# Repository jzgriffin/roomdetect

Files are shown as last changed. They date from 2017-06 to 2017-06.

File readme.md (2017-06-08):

# CS120B

This repository contains the quarter project that I completed in CS120B,
Introduction to Embedded Systems, at UC Riverside in spring 2017.  The
project was a room detector using a trained statistical model running on
a pair of ATmega1284p microcontrollers.  For more information, see the
full report in the report directory.

## Ownership

I acknowledge all content contained herein, excluding template or
example code, is my own original work.

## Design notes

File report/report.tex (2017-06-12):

\documentclass{article}

\usepackage{etoolbox}
\usepackage{float}
\usepackage{geometry}
\usepackage{graphicx}
\usepackage{pgf}
\usepackage{tikz}

\newtoggle{TASKSPECONLY}

\geometry{margin=1in}

\graphicspath{ {figures/}{photos/} }

\usetikzlibrary{arrows}
\usetikzlibrary{automata}
\usetikzlibrary{fit}
\usetikzlibrary{positioning}
\tikzset{initial text={}}

\title{Report: Room Detector}
\author{Jeremiah Griffin}
\date{Spring 2017}

\begin{document}

\pagenumbering{gobble}
\maketitle
\newpage

\pagenumbering{roman}
\tableofcontents
\newpage

\pagenumbering{arabic}

\section{Introduction}

The room detector uses inputs from several sensors to determine what
room or environment the device is currently in.  It uses a statistical
model to associate ambient factors with a user-defined room number.  The
network must be trained by the user before it may be used.  This is done
online by placing the device in each room to be detected, entering
training mode, associating either a new or existing room number with the
training data, and then moving the device through the room.  The longer
the device is trained, the more accurate its classifications become.
Once training is complete, the device may enter detection mode and be
moved between any of the trained rooms.  If brought to an untrained
room, it will make its best guess at classifying the room as one that
was trained.

\begin{figure}[h]
  \centering
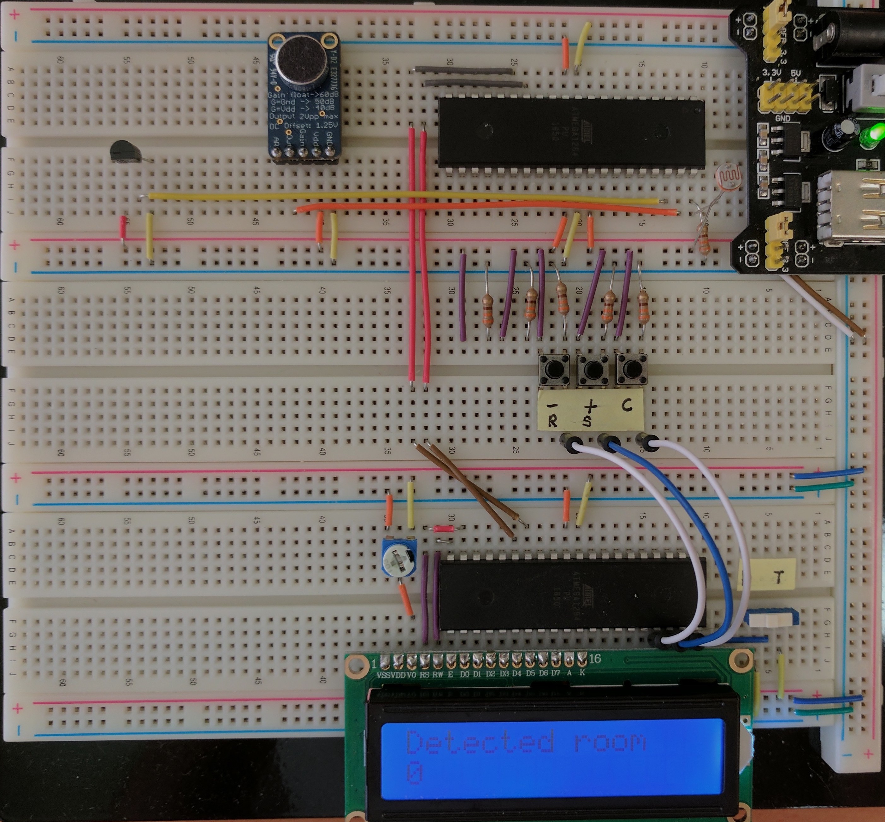
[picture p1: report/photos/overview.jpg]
  \noindent
  \caption{Overview photo of project hardware}
  \label{photo:1}
\end{figure}

\section{Hardware}

\subsection{Parts}

The hardware components that were used in this project are listed below.
The equipment that was not taught as part of the course material is
listed in bold.

\begin{table}[h!]
  \centering
  \begin{tabular}{llr}
    Part Number & Component & Quantity \\
    \hline
    ATmega1284p             & Microcontroller                  & 2 \\
                            & SPDT toggle switch               & 1 \\
                            & SPST push-down button            & 3 \\
                            & 10K\Omega\ trimmer potentiometer & 1 \\
                            & 330\Omega\ 10\% resistor         & 4 \\
                            & CdS photoresistor                & 1 \\
    LCM-S01602DTR/M         & Liquid crystal display           & 1 \\
    \textbf{TMP36}          & Temperature sensor               & 1 \\
    \textbf{CMA-4544PF-W}   & Electret microphone              & 1 \\
    \textbf{MAX9814}        & Microphone amplifier             & 1
  \end{tabular}
  \caption{Listing of parts used in design}
  \label{table:1}
\end{table}

\subsection{Pinout}

\begin{figure}[H]
  \centering
  \noindent
  \caption{Pinout and schematic for project}
  \label{schematic:1}
\end{figure}

\section{Software}

The software designed for this project was implemented using the PES
standard.  The overall design as a task diagram is included below.

\begin{figure}[H]
  \centering
  \noindent
  \caption{Task diagram for project}
  \label{task:1}
\end{figure}

The master and compute tasks run on their respective microcontrollers.
The common tasks run independently on both microcontrollers, being part
of a static library linked to by both microcontroller applications and
instantiated in their task schedulers.  The inputs and outputs for the
common LCD, USART TX, USART RX, and packet RX tasks were excluded from
this diagram for brevity but are documented in their task descriptions.

In the following sections, the individual tasks from the above diagram
are briefly described in addition to their inputs and outputs.  The
state machines for these tasks are presented in appendix \ref{app.sm}.

\subsection{Tasks}

\toggletrue{TASKSPECONLY}

\subsubsection{Master Mode Task}
\input{figures/master_mode_task.tex}

Sets \verb#device_mode# to \verb#DETECTION# if \verb#PA0# is low and to
\verb#TRAINING# if it's high.  This controls which of the detection and
training tasks is enabled.

\subsubsection{Master Detection Task}
\input{figures/master_detection_task.tex}

Operates when \verb#device_mode# is \verb#DETECTION#.  Receives
detection packets from the compute microcontroller.  Responds to the
save, reset, and erase buttons by sending the appropriate packets to the
compute microcontroller to adjust the model.

\subsubsection{Master Training Task}
\input{figures/master_training_task.tex}

Operates when \verb#device_mode# is \verb#TRAINING#.  Responds to the
increment, decrement, and confirm buttons by adjusting the training room
and sending the appropriate packets to the compute microcontroller to
begin and end training.  Sets \verb#is_training# to true when training.

\subsubsection{Master Display Task}
\input{figures/master_display_task.tex}

Outputs messages to the LCD according to the current state and detected
or training room.  Controlled by the detection and training tasks.

\subsubsection{Compute Mode Task}
\input{figures/compute_mode_task.tex}

Sets \verb#device_mode# to \verb#DETECTION# when a stop-training packet
is received and to \verb#TRAINING# when a start-training packet is
received.  Sets \verb#training_room# to the room indicated in the
start-training packet.

\subsubsection{Compute Reading Task}
\input{figures/compute_reading_task.tex}

Samples from the analog inputs in sequence when
\verb#should_poll_readings# is true to create the \verb#reading_vector#.
Calculates the mean of 16 samples through time to smooth noise.
Indicates when the reading vector is populated by setting
\verb#are_readings_ready# to true.

\subsubsection{Compute Detection Task}
\input{figures/compute_detection_task.tex}

Classifies the current reading vector using the classification model
when \verb#are_readings_ready# is high and \verb#device_mode# is
\verb#DETECTION#.  Outputs the classification result to
\verb#detected_room#.

\subsubsection{Compute Training Task}
\input{figures/compute_training_task.tex}

Integrates the current reading vector into the classification model when
\verb#are_readings_ready# is high and \verb#device_mode# is
\verb#TRAINING#.

\subsubsection{Common LCD Task}
\input{figures/common_lcd_task.tex}

Clears the LCD when \verb#should_lcd_clear# is true.  Writes the
contents of \verb#lcd_buffer# to the LCD at \verb#lcd_position# when
\verb#should_lcd_write# is true.  Sets \verb#is_lcd_ready# to true when
the current operation is complete.

\subsubsection{Common USART TX Task}
\input{figures/common_usart_tx_task.tex}

Transmits bytes over USART from the TX queue.

\subsubsection{Common USART RX Task}
\input{figures/common_usart_rx_task.tex}

Receives bytes from USART into the RX queue.

\subsubsection{Common Packet RX Task}
\input{figures/common_usart_packet_rx_task.tex}

Identifies and receives packets from the USART RX queue into the packet
RX queue.  When active, non-packet bytes are discarded from the
queue--thus only packet communication is possible when scheduled.

\section{Complexities}

\subsection{Complete}

\begin{itemize}

  \item Using EEPROM to persist the classification model state

  \item Using USART to offload computation to a dedicated
    microcontroller

  \item Using ADC multiplexing to collect analog readings from multiple
    sensors

  \item Using a temperature sensor and microphone obtained outside of
    the lab kit

  \item Using a statistical model to perform input classification using
    fixed-point arithmetic

\end{itemize}

\subsection{Incomplete}

\begin{itemize}

  \item Using a neural network to perform input classification using
    fixed-point arithmetic \\
    This complexity could not be completed due to hardware limitations.
    Its role in the project was instead filled by the statistical model
    listed above.  The intended design for the neural network was a
    multi-layer feed-forward network, with one input layer of size 4,
    one hidden layer of size 10 with a linear activation function, one
    hidden layer of size 10 with a hyperbolic tangent activation
    function, one hidden layer of size 16 with a linear activation
    function, and one output layer of size 16 with a softmax activation
    function.  This topology was chosen as the best for fulfilling the
    goal of classifying three inputs, with one bias input, into one of
    16 outputs.  However, this network proved too large for the ATmega
    to process.  When including the amount of memory necessary for
    storing training state, the network became too large for storage in
    the ATmega's 16 kilobyte SRAM.  Additionally, even using fixed-point
    arithmetic in place of traditional floating point, the times for
    classification became slower than was considered acceptable and the
    times for training made it obvious that training would only be
    possible offline using a faster device, which was deemed to be
    beyond the scope of this project.  As a result of these limitations,
    the neural network was replaced with a simpler statistical model at
    the cost of accuracy and robustness when faced with input noise.

\end{itemize}

\section{Links}

\begin{description}

  \item [Demonstration Video] https://youtu.be/Kw6NZRzlpkQ

  \item [GitHub Repository] https://github.com/nokurn/roomdetect

\end{description}

\section{Known Issues}

\begin{itemize}

  \item The classification algorithm does not cope well with noise and
    may confuse environments with a large degree of noise as being
    equivalent regardless of the specifics of that noise.

  \item The temperature sensor is not measured with sufficient precision
    for its readings to adequately influence the results of the
    classification.

  \item The microphone primarily distinguishes between noisy and quiet
    environments with no consideration of the qualities of the sound
    such as timbre and pitch.

  \item The classifier most heavily relies on the measurements from the
    photo-resistor, despite unbiased treatment of all readings in the
    input vector.  This is likely due to the aforementioned reasons:
    low analog precision and the need for pre-processing of some
    readings.

\end{itemize}

\section{Future Work}

\begin{itemize}

  \item The largest improvement might come from replacing the compute
    microcontroller with a higher-power compute unit, possibly
    integrating floating-point arithmetic, and using a more robust
    classification model such as a neural network.

  \item By using an external analog-digital converter with higher
    precision, or simply replacing the ATmega with a microcontroller
    with a higher-precision integrated ADC, sensors with small output
    ranges would contribute more to the accuracy and confidence of the
    device's classifications.  This would reflect immediately in the
    ability of the device to distinguish between environments with
    slightly different temperatures.

  \item Applying a Fourier transform to the microphone signal and using
    the individual components as input to the classifier would improve
    the quality of classifications with regard to environmental sounds.
    For example, if one room contains several computers with spinning
    fans and another room has a single ceiling fan, yet the volume level
    in both rooms is similar, a Fourier analysis of the sound waves
    would enable the classifier to distinguish between the two by the
    timbre and pitch of the sound in addition to its loudness.

  \item Adding additional sensors would increase the size of the
    classifier's feature vector and its accuracy.  Barometric pressure,
    humidity, altitude, or even GPS would be likely candidates for
    inclusion in the system.

\end{itemize}

\appendix

\section{Appendix: State Machines}
\label{app.sm}

\togglefalse{TASKSPECONLY}

In the following state machines, transitions without conditions should
be interpreted to be else-transitions unless the state only has one
outgoing transition, in which case the transition is unconditional.

\subsection{Master Microcontroller}
\label{app.sm.master}

\begin{figure}[H]
  \caption{State machine for master mode task}
  \input{figures/master_mode_task.tex}
  \label{sm:1}
\end{figure}

\begin{figure}[H]
  \caption{State machine for master detection task}
  \input{figures/master_detection_task.tex}
  \label{sm:2}
\end{figure}

\begin{figure}[H]
  \caption{State machine for master training task}
  \input{figures/master_training_task.tex}
  \label{sm:3}
\end{figure}

\begin{figure}[H]
  \caption{State machine for master display task}
  \input{figures/master_display_task.tex}
  \label{sm:4}
\end{figure}

\subsection{Compute Microcontroller}
\label{app.sm.compute}

\begin{figure}[H]
  \caption{State machine for compute mode task}
  \input{figures/compute_mode_task.tex}
  \label{sm:5}
\end{figure}

\begin{figure}[H]
  \caption{State machine for compute reading task}
  \input{figures/compute_reading_task.tex}
  \label{sm:6}
\end{figure}

\begin{figure}[H]
  \caption{State machine for compute detection task}
  \input{figures/compute_detection_task.tex}
  \label{sm:7}
\end{figure}

\begin{figure}[H]
  \caption{State machine for compute training task}
  \input{figures/compute_training_task.tex}
  \label{sm:8}
\end{figure}

\subsection{Common Infrastructure}
\label{app.sm.common}

\begin{figure}[H]
  \caption{State machine for common LCD task}
  \input{figures/common_lcd_task.tex}
  \label{sm:9}
\end{figure}

\begin{figure}[H]
  \caption{State machine for common USART TX task}
  \input{figures/common_usart_tx_task.tex}
  \label{sm:10}
\end{figure}

\begin{figure}[H]
  \caption{State machine for common USART RX task}
  \input{figures/common_usart_rx_task.tex}
  \label{sm:11}
\end{figure}

\begin{figure}[H]
  \caption{State machine for common USART packet RX task}
  \input{figures/common_usart_packet_rx_task.tex}
  \label{sm:12}
\end{figure}

\end{document}

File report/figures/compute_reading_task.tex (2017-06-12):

\begin{flushleft}
  \begin{description}
    \item [Input]
      \verb#should_poll_readings: bool#;
      \verb#adc#
    \item [Output]
      \verb#reading_vector: accum[]#;
      \verb#are_readings_ready: bool#
    \item [Local]
      \verb#readings: accum[]#;
      \verb#index: size#;
      \verb#samples: size#
    \item [Period] 1 ms
  \end{description}
\end{flushleft}

\iftoggle{TASKSPECONLY}{}
{
\begin{center}
  \begin{tikzpicture}[->,>=stealth',
      shorten >=1pt,
      node distance=41mm,
      auto,
      on grid,
      semithick]

    \node[state,initial]
      (Initial) {Initial};
    \node[state]
      (Configure) [right=of Initial] {Configure};
    \node[state]
      (Standby) [right=of Configure] {Standby};
    \node[state]
      (Poll) [below of=Standby] {Poll};
    \node[state]
      (Start) [below of=Initial] {Start};
    \node[state]
      (Wait) [below of=Start] {Wait};
    \node[state]
      (Read) [below of=Poll] {Read};
    \node[state]
      (Next) [below of=Read] {Next};
    \node[state]
      (Output) [below of=Wait] {Output};

    \path[->]
      (Initial) edge node {} (Configure)
      (Configure) edge node {} (Standby)
      (Standby) edge node {should\_poll\_readings} (Poll)
      (Standby) edge [loop right] node {} (Standby)
      (Poll) edge node {} (Start)
      (Start) edge node {} (Wait)
      (Wait) edge node {is\_adc\_ready()} (Read)
      (Wait) edge [loop left] node {} (Wait)
      (Read) edge [align=left] node {index ==\\MODEL\_VECTOR\_SIZE} (Next)
      (Read) edge node {} (Start)
      (Next) edge [align=left] node {samples ==\\SAMPLE\_SIZE} (Output)
      (Next) edge [bend left] node {} (Start)
      (Output) edge [bend left=20] node {} (Standby);

  \end{tikzpicture}
\end{center}

}

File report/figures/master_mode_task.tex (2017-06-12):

\begin{flushleft}
  \begin{description}
    \item [Input]
      \verb#PA0#
    \item [Output]
      \verb#device_mode: enum#
    \item [Period] 16 ms
  \end{description}
\end{flushleft}

\iftoggle{TASKSPECONLY}{}
{
\begin{tikzpicture}[->,>=stealth',
    shorten >=1pt,
    node distance=40mm,
    auto,
    on grid,
    semithick]

  \node[state,initial]
    (Initial) {Initial};
  \node[state]
    (Configure) [right=of Initial] {Configure};
  \node[state,label={[align=left]above:{device\_mode =\\DETECTION}}]
    (Detection) [right=of Configure] {Detection};
  \node[state,label={[align=left]above:{device\_mode =\\TRAINING}}]
    (Training) [right=of Detection] {Training};

  \path[->]
    (Initial)   edge node {}     (Configure)
    (Configure) edge node {!PA0} (Detection)
    (Configure) edge [bend right=90] node [below] {PA0}  (Training)
    (Detection) edge [loop below] node {!PA0} (Detection)
    (Detection) edge [bend left] node {PA0}  (Training)
    (Training)  edge [bend left] node {!PA0} (Detection)
    (Training)  edge [loop right] node {PA0}  (Training);

\end{tikzpicture}
}

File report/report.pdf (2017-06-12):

# Report: Room Detector

Jeremiah Griffin

Spring 2017

## Contents

1 Introduction | 1
2 Hardware | 2
3 Software | 3
4 Complexities | 6
5 Links | 7
6 Known Issues | 7
7 Future Work | 7
A Appendix: State Machines | 7

i

## 1 Introduction

The room detector uses inputs from several sensors to determine what room or environment the device is currently in. It uses a statistical model to associate ambient factors with a user-defined room number. The network must be trained by the user before it may be used. This is done online by placing the device in each room to be detected, entering training mode, associating either a new or existing room number with the training data, and then moving the device through the room. The longer the device is trained, the more accurate its classifications become. Once training is complete, the device may enter detection mode and be moved between any of the trained rooms. If brought to an untrained room, it will make its best guess at classifying the room as one that was trained.


Figure 1: Overview photo of project hardware

## 2 Hardware

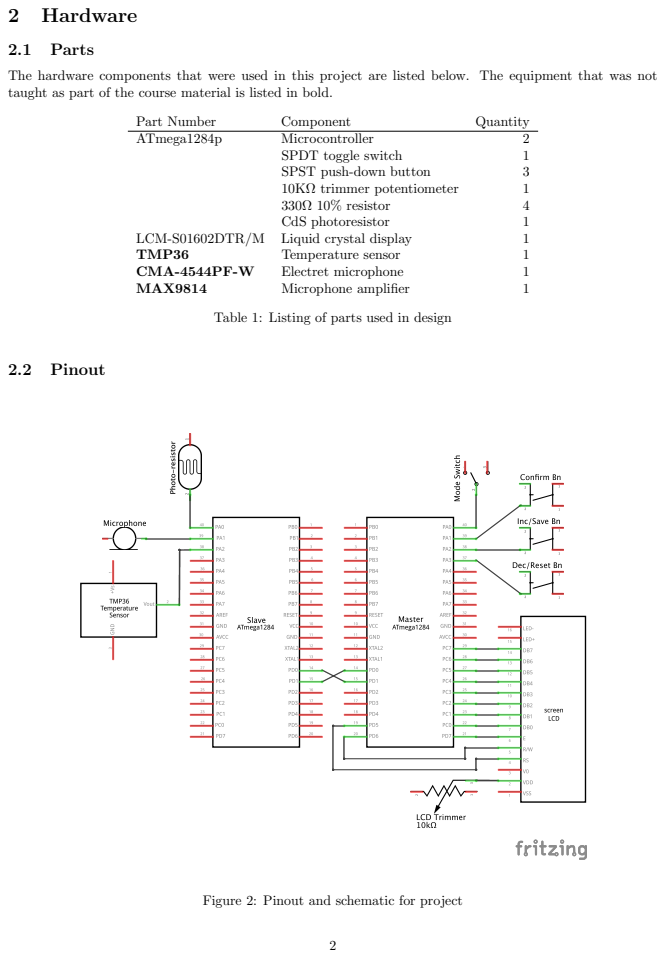
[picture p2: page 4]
2.1 Parts; Part Number; Component; Quantity; ATmega1284p; Microcontroller; SPDT toggle switch; SPST push-down button; 10KΩ trimmer potentiometer; 330Ω 10% resistor; CdS photoresistor; LCM-S01602DTR/M; Liquid crystal display; TMP36; Temperature sensor; CMA-4544PF-W; Electret microphone; MAX9814; Microphone amplifier; 2.2 Pinout

The hardware components that were used in this project are listed below. The equipment that was not
taught as part of the course material is listed in bold.

Table 1: Listing of parts used in design

Figure 2: Pinout and schematic for project

## 3 Software

The software designed for this project was implemented using the PES standard. The overall design as a

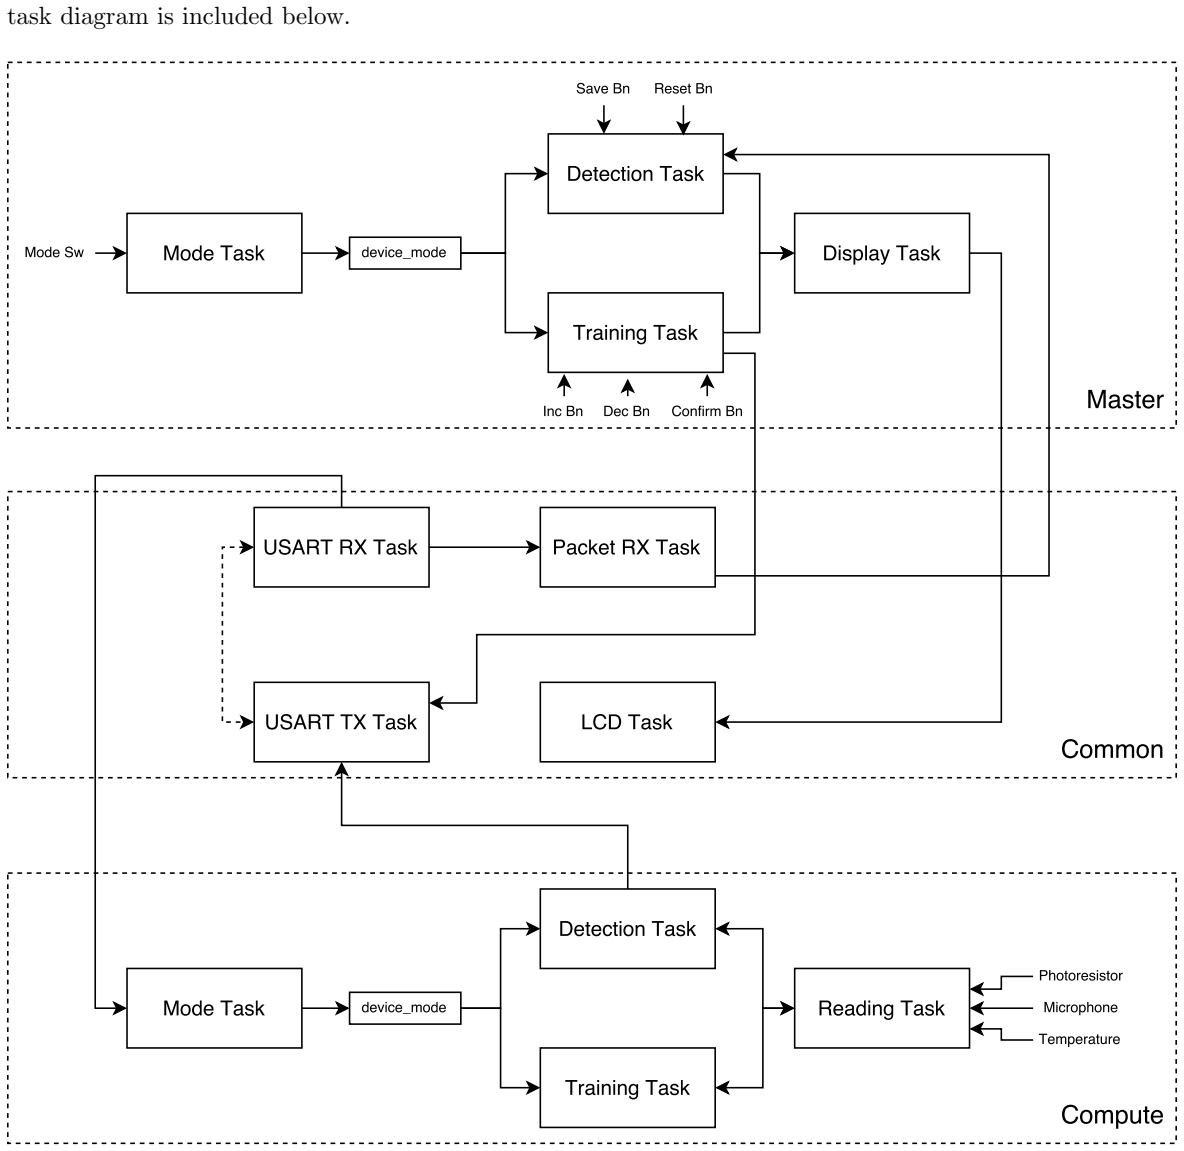
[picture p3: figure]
task diagram is included below.

Figure 3: Task diagram for project

The master and compute tasks run on their respective microcontrollers. The common tasks run independently on both microcontrollers, being part of a static library linked to by both microcontroller applications and instantiated in their task schedulers. The inputs and outputs for the common LCD, USART TX, US-ART RX, and packet RX tasks were excluded from this diagram for brevity but are documented in their task descriptions.
In the following sections, the individual tasks from the above diagram are briefly described in addition to their inputs and outputs. The state machines for these tasks are presented in appendix A.

### 3.1 Tasks

### 3.1.1 Master Mode Task

Input PA0

Output device_mode: enum

Period 16 ms

Sets device_mode to DETECTION if PA0 is low and to TRAINING if it’s high. This controls which of the detection and training tasks is enabled.

### 3.1.2 Master Detection Task

Input device_mode; PA2; PA3

Output detected_room: uint8; usart_tx_queue

Local tick_count: uint16

Period 20 ms

Operates when device_mode is DETECTION. Receives detection packets from the compute microcontroller. Responds to the save, reset, and erase buttons by sending the appropriate packets to the compute microcontroller to adjust the model.

### 3.1.3 Master Training Task

Input device_mode; PA1; PA2; PA3

Output training_room: uint8; is_training: bool; usart_tx_queue

Local tick_count: uint16

Period 20 ms

Operates when device_mode is TRAINING. Responds to the increment, decrement, and confirm buttons by adjusting the training room and sending the appropriate packets to the compute microcontroller to begin and end training. Sets is_training to true when training.

### 3.1.4 Master Display Task

Input detected_room; training_room; is_training; should_display_save; should_display_reset; should_display_erase; is_lcd_ready

Output should_lcd_clear; should_lcd_write; lcd_buffer; lcd_position

Local last_room: uint8

Period 20 ms

Outputs messages to the LCD according to the current state and detected or training room. Controlled by the detection and training tasks.

### 3.1.5 Compute Mode Task

Input usart_packet_rx_queue

Output device_mode: enum; training_room: uint8

Period 16 ms

Sets device_mode to DETECTION when a stop-training packet is received and to TRAINING when a start-training packet is received. Sets training_room to the room indicated in the start-training packet.

### 3.1.6 Compute Reading Task

Input should_poll_readings: bool; adc

Output reading_vector: accum[]; are_readings_ready: bool

Local readings: accum[]; index: size; samples: size

Period 1 ms

Samples from the analog inputs in sequence when should_poll_readings is true to create the reading_vector. Calculates the mean of 16 samples through time to smooth noise. Indicates when the reading vector is populated by setting are_readings_ready to true.

### 3.1.7 Compute Detection Task

Input device_mode; reading_vector; are_readings_ready

Output detected_room: uint8; should_poll_readings

Period 16 ms

Classifies the current reading vector using the classification model when are_readings_ready is high and device_mode is DETECTION. Outputs the classification result to detected_room.

### 3.1.8 Compute Training Task

Input device_mode; reading_vector; are_readings_ready; training_room: uint8

Output should_poll_readings

Period 16 ms

Integrates the current reading vector into the classification model when are_readings_ready is high and device_mode is TRAINING.

### 3.1.9 Common LCD Task

Input should_lcd_clear: bool; should_lcd_write: bool; lcd_buffer: char[]; lcd_position: uint8

Output is_lcd_ready: bool

Local index: size

Period 2 ms

Clears the LCD when should_lcd_clear is true. Writes the contents of lcd_buffer to the LCD at lcd_position when should_lcd_write is true. Sets is_lcd_ready to true when the current operation is complete.

### 3.1.10 Common USART TX Task

Input usart_tx_queue: uint8[]; usart_tx_queue_size: size; usart_tx_queue_head: size; usart_tx_queue_tail: size

Output usart_tx_queue

Period 1 ms

Transmits bytes over USART from the TX queue.

### 3.1.11 Common USART RX Task

Input usart_rx_queue

Output usart_rx_queue: uint8[]; usart_rx_queue_size: size; usart_rx_queue_head: size; usart_rx_queue_tail: size

Period 1 ms

Receives bytes from USART into the RX queue.

### 3.1.12 Common Packet RX Task

Input usart_rx_queue

Output usart_packet_rx_queue: usart_packet[]; usart_packet_rx_queue_size: size; usart_packet_rx_queue_head: size; usart_packet_rx_queue_tail: size

Locals packet: uint8[]; size: size; target_size: size; data_size: size

Period 1 ms

Identifies and receives packets from the USART RX queue into the packet RX queue. When active, non-packet bytes are discarded from the queue–thus only packet communication is possible when scheduled.

## 4 Complexities

### 4.1 Complete

- Using EEPROM to persist the classification model state
- Using USART to offload computation to a dedicated microcontroller
- Using ADC multiplexing to collect analog readings from multiple sensors
- Using a temperature sensor and microphone obtained outside of the lab kit
- Using a statistical model to perform input classification using fixed-point arithmetic

### 4.2 Incomplete

- Using a neural network to perform input classification using fixed-point arithmetic
This complexity could not be completed due to hardware limitations. Its role in the project was instead filled by the statistical model listed above. The intended design for the neural network was a multi-layer feed-forward network, with one input layer of size 4, one hidden layer of size 10 with a linear activation function, one hidden layer of size 10 with a hyperbolic tangent activation function, one hidden layer of size 16 with a linear activation function, and one output layer of size 16 with a softmax activation function. This topology was chosen as the best for fulfilling the goal of classifying three inputs, with one bias input, into one of 16 outputs. However, this network proved too large for the ATmega to process. When including the amount of memory necessary for storing training state, the network became too large for storage in the ATmega’s 16 kilobyte SRAM. Additionally, even using fixed-point arithmetic in place of traditional floating point, the times for classification became slower than was considered acceptable and the times for training made it obvious that training would only be possible offline using a faster device, which was deemed to be beyond the scope of this project. As a result of these limitations, the neural network was replaced with a simpler statistical model at the cost of accuracy and robustness when faced with input noise.

## 5 Links

Demonstration Video https://youtu.be/Kw6NZRzlpkQ

GitHub Repository https://github.com/nokurn/roomdetect

## 6 Known Issues

- The classification algorithm does not cope well with noise and may confuse environments with a large degree of noise as being equivalent regardless of the specifics of that noise.
- The temperature sensor is not measured with sufficient precision for its readings to adequately influence the results of the classification.
- The microphone primarily distinguishes between noisy and quiet environments with no consideration of the qualities of the sound such as timbre and pitch.
- The classifier most heavily relies on the measurements from the photo-resistor, despite unbiased treatment of all readings in the input vector. This is likely due to the aforementioned reasons: low analog precision and the need for pre-processing of some readings.

## 7 Future Work

- The largest improvement might come from replacing the compute microcontroller with a higher-power compute unit, possibly integrating floating-point arithmetic, and using a more robust classification model such as a neural network.
- By using an external analog-digital converter with higher precision, or simply replacing the ATmega with a microcontroller with a higher-precision integrated ADC, sensors with small output ranges would contribute more to the accuracy and confidence of the device’s classifications. This would reflect immediately in the ability of the device to distinguish between environments with slightly different temperatures.
- Applying a Fourier transform to the microphone signal and using the individual components as input to the classifier would improve the quality of classifications with regard to environmental sounds. For example, if one room contains several computers with spinning fans and another room has a single ceiling fan, yet the volume level in both rooms is similar, a Fourier analysis of the sound waves would enable the classifier to distinguish between the two by the timbre and pitch of the sound in addition to its loudness.
- Adding additional sensors would increase the size of the classifier’s feature vector and its accuracy. Barometric pressure, humidity, altitude, or even GPS would be likely candidates for inclusion in the system.

## A Appendix: State Machines

In the following state machines, transitions without conditions should be interpreted to be else-transitions unless the state only has one outgoing transition, in which case the transition is unconditional.

A.1 Master Microcontroller

Figure 4: State machine for master mode task

Input PA0

Output device_mode: enum

Period 16 ms

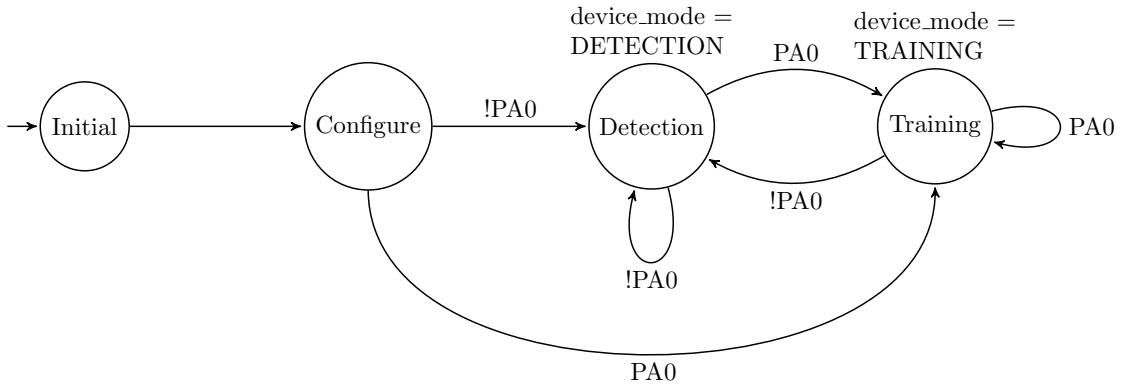
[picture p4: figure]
Initial; Configure; Detection; device mode = DETECTION; Training; device mode = TRAINING

Figure 5: State machine for master detection task

Input device_mode; PA2; PA3

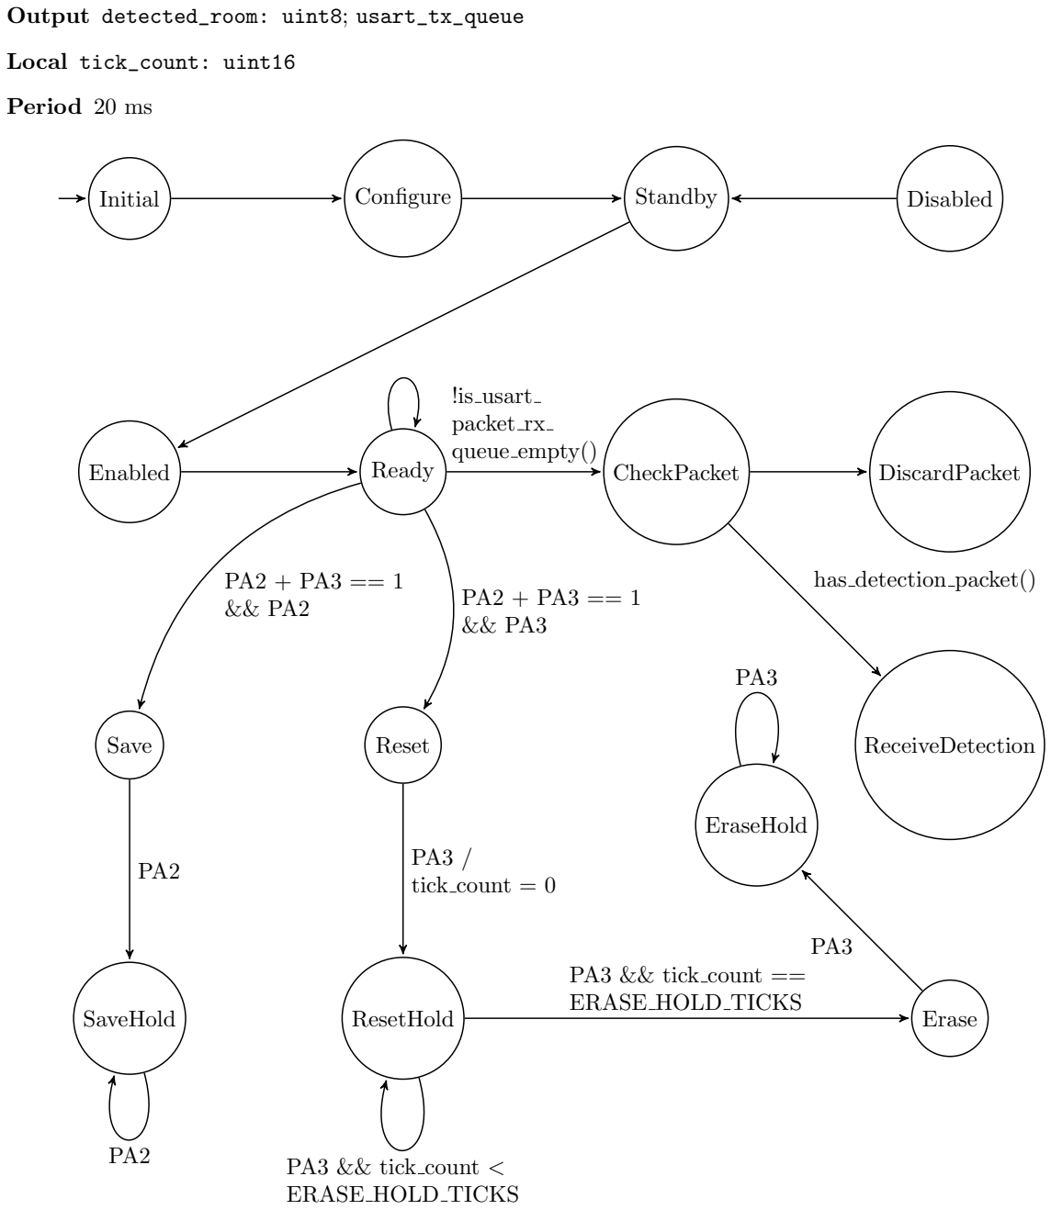
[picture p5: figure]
Output detected_room: uint8; usart_tx_queue; Local tick_count: uint16; Period 20 ms; Initial; Configure; Standby; Disabled; Enabled; Ready; Reset; ResetHold; Save; SaveHold; CheckPacket; DiscardPacket; ReceiveDetection; Erase; EraseHold; !is usart packet rx queue empty(); PA3 / tick count = 0; PA3 && tick count == ERASE HOLD TICKS; PA3 && tick count < ERASE HOLD TICKS; has detection packet()

The following transitions have been omitted for clarity: from all states to the Disabled state, under the condition that device mode != DETECTION; and the else-transitions from the DiscardPacket, ReceiveDetection, Save, Reset, Erase, SaveHold, ResetHold, and EraseHold states to the Ready state.

Figure 6: State machine for master training task

Input device_mode; PA1; PA2; PA3

Output training_room: uint8; is_training: bool; usart_tx_queue

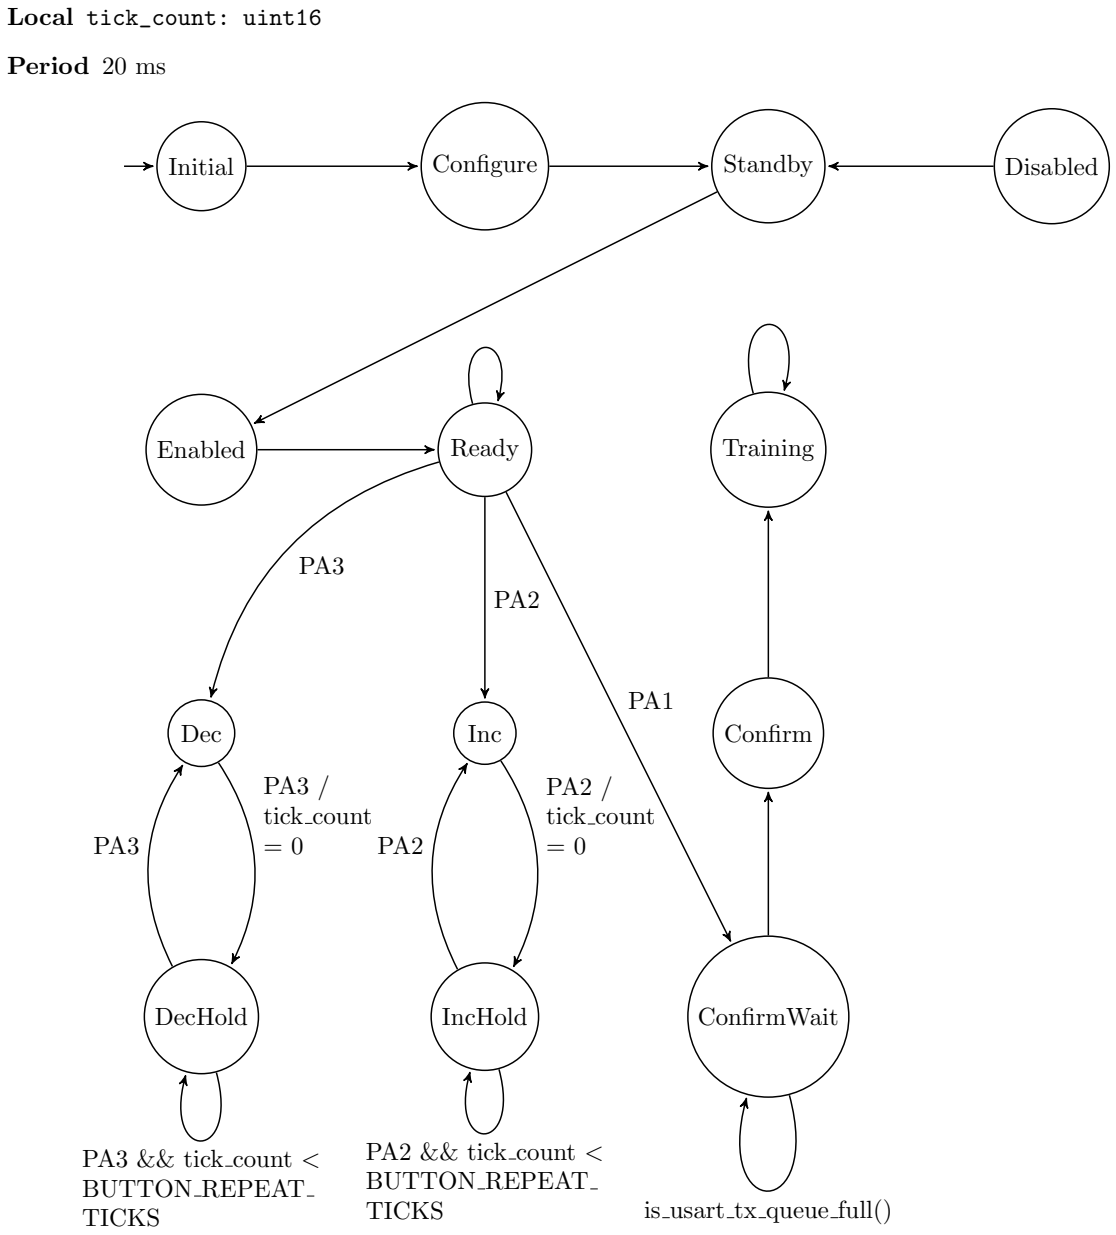
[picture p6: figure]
Local tick_count: uint16; Period 20 ms; Initial; Configure; Standby; Disabled; Enabled; Ready; Inc; IncHold; Dec; DecHold; Training; Confirm; ConfirmWait; PA2 / tick count; PA2 && tick count < BUTTON REPEAT TICKS; PA3 / tick count; PA3 && tick count < BUTTON REPEAT; TICKS; is usart tx queue full()

The following transitions have been omitted for clarity: from all states to the Disabled state, under the condition that device mode != TRAINING; and the else-transitions from the Inc, IncHold, Dec, and DecHold states to the Ready state. The transition conditions from the Ready state to the Dec, Inc, and ConfirmWait states are also conjoined with the condition that PA1 + PA2 + PA3 == 1. The transition conditions from the DecHold and IncHold states to the Dec and Inc states, respectively, are also conjoined with the condition that tick count == BUTTON REPEAT TICKS.

Figure 7: State machine for master display task

Input detected_room; training_room; is_training; should_display_save; should_display_reset; should_display_erase; is_lcd_ready

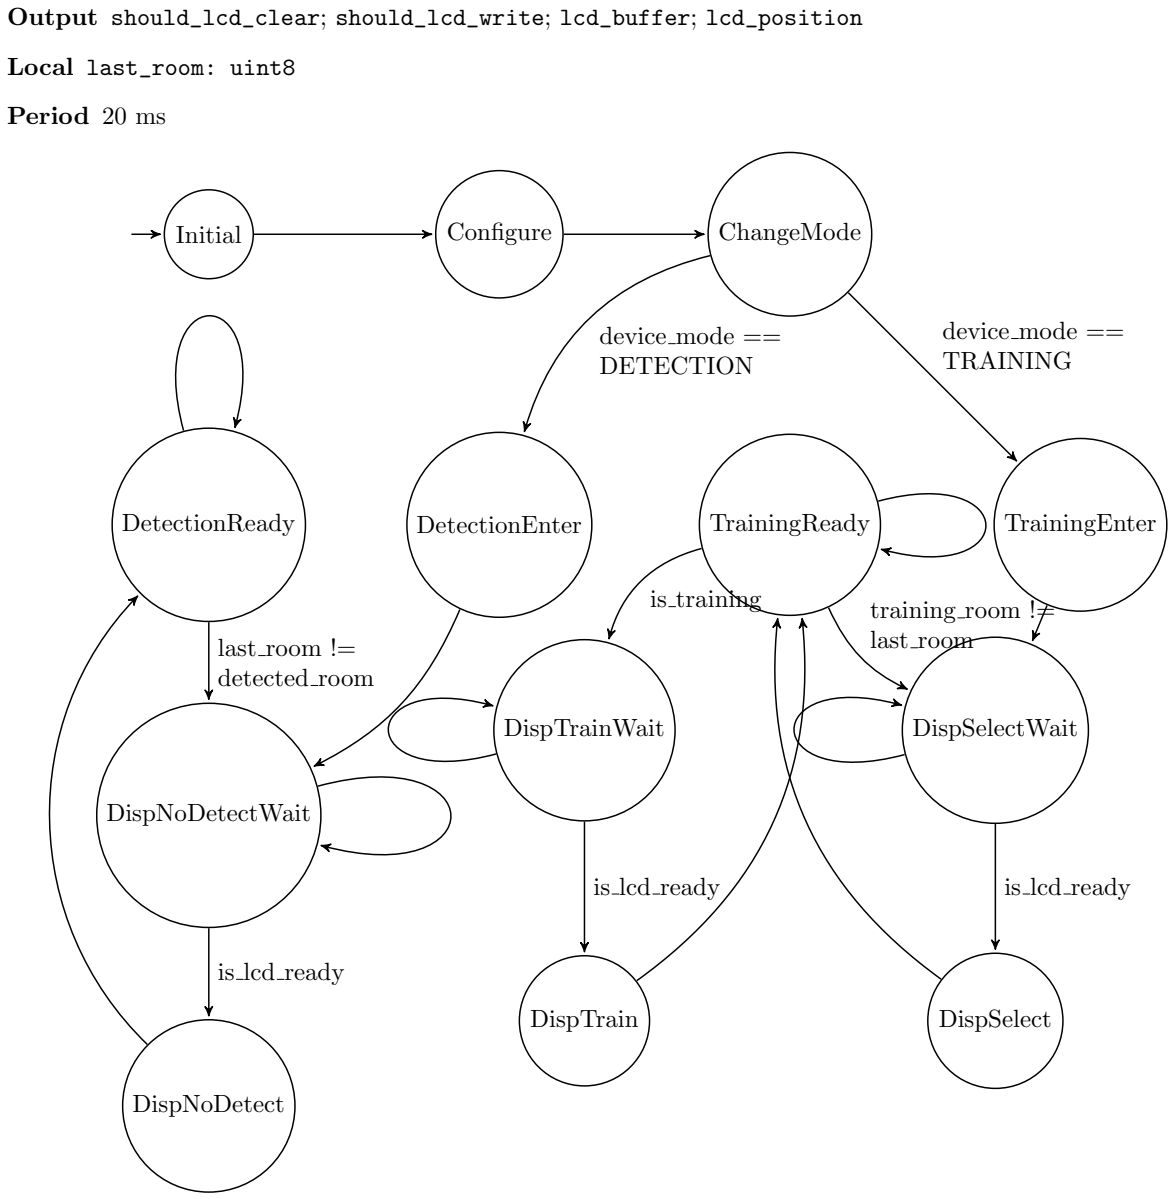
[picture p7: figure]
Output should_lcd_clear; should_lcd_write; lcd_buffer; lcd_position; Local last_room: uint8; Period 20 ms; Initial; Configure; ChangeMode; DetectionReady; DetectionEnter; DispNoDetectWait; DispNoDetect; TrainingReady; TrainingEnter; DispSelectWait; DispSelect; DispTrainWait; DispTrain; device mode == DETECTION; device mode == TRAINING; last room != detected room; is lcd ready; training room != last room; is training

The following transitions have been omitted for clarity: from all states to the ChangeMode state, under the condition that device mode is different from the expected mode for the given state. The DispNoDetectWait and DispNoDetect states are duplicated, including transitions, for the following similar states: Detect, Save, Reset, and Erase. These redundant states have been omitted for clarity.

A.2 Compute Microcontroller

Figure 8: State machine for compute mode task

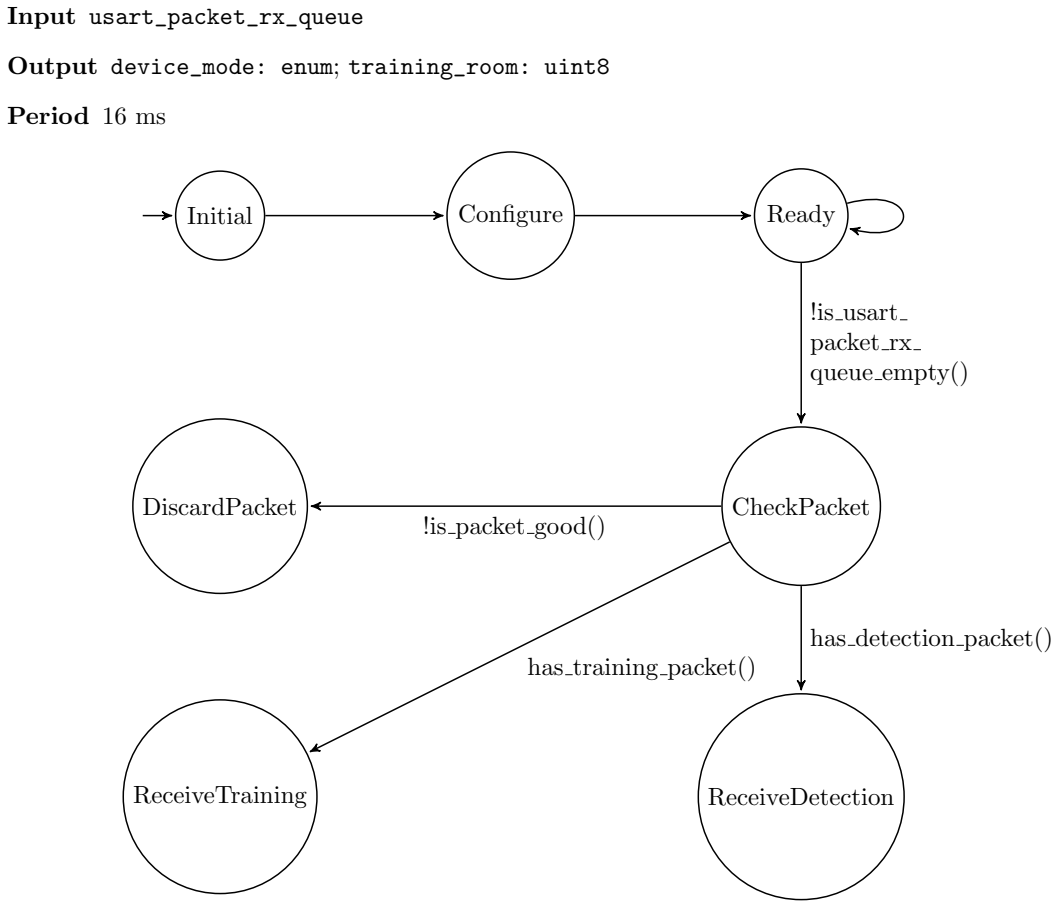
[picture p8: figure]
Input usart_packet_rx_queue; Output device_mode: enum; training_room: uint8; Period 16 ms; Initial; Configure; Ready; DiscardPacket; CheckPacket; ReceiveTraining; ReceiveDetection; !is usart packet rx queue empty(); !is packet good(); has detection packet(); has training packet()

The following transitions have been omitted for clarity: from the DiscardPacket, ReceiveDetection, and ReceiveTraining states to the Ready state under any condition.

Figure 9: State machine for compute reading task

Input should_poll_readings: bool; adc

Output reading_vector: accum[]; are_readings_ready: bool

Local readings: accum[]; index: size; samples: size

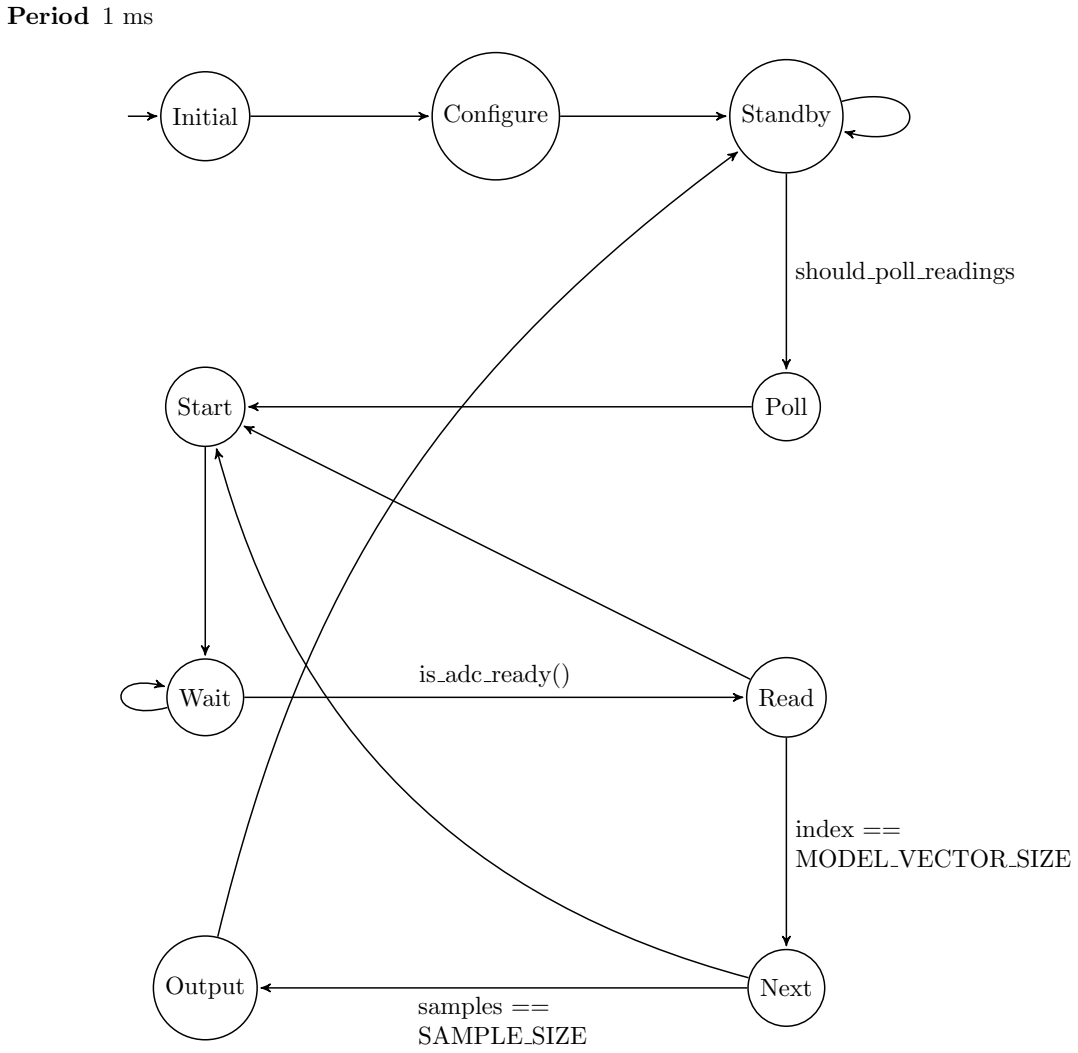
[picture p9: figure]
Period 1 ms; Initial; Configure; Standby; Start; Poll; Wait; Read; Output; Next; should poll readings; is adc ready(); index == MODEL VECTOR SIZE; samples == SAMPLE SIZE

Figure 10: State machine for compute detection task

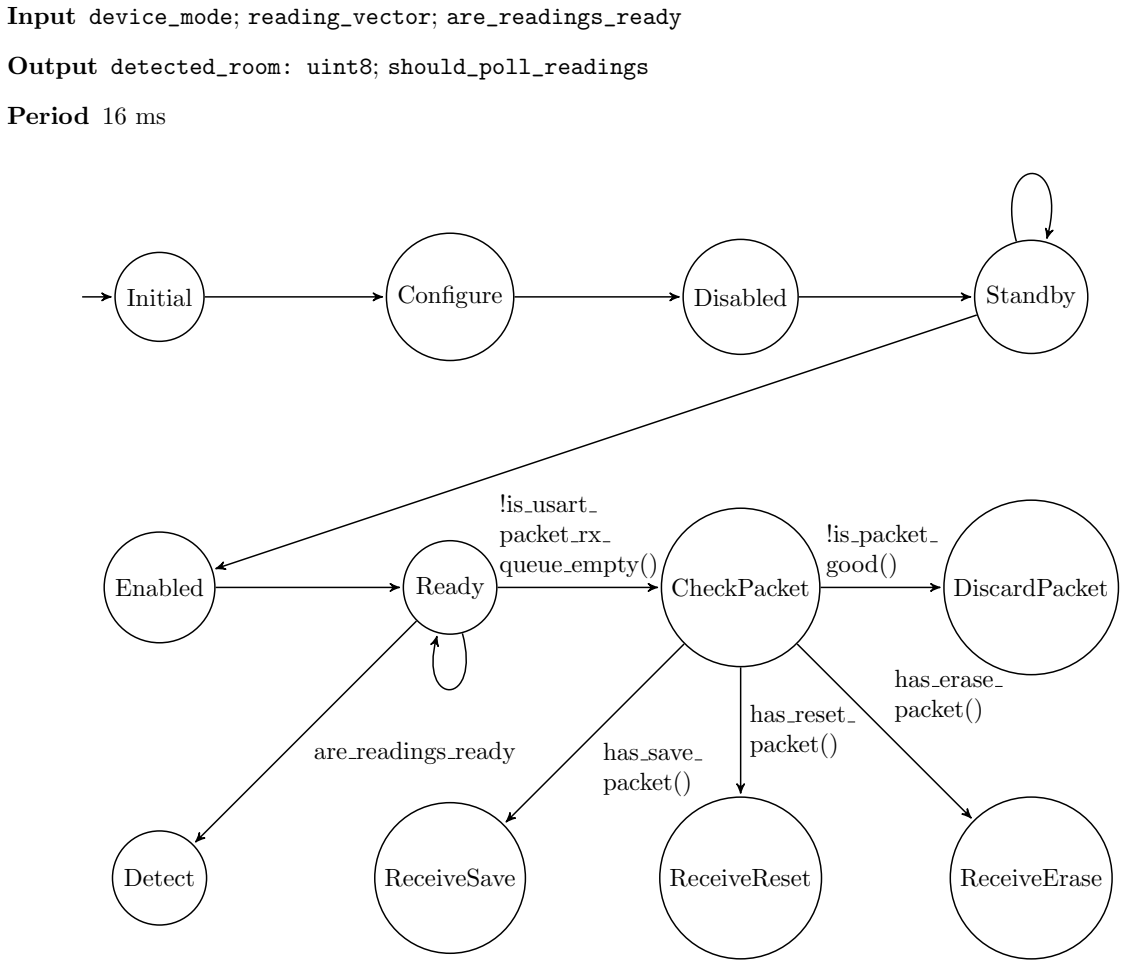
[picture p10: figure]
Input device_mode; reading_vector; are_readings_ready; Output detected_room: uint8; should_poll_readings; Period 16 ms; Initial; Configure; Disabled; Standby; Enabled; Ready; Detect; CheckPacket; DiscardPacket; ReceiveSave; ReceiveReset; ReceiveErase; !is usart packet rx queue empty(); are readings ready; !is packet good(); has save packet(); has reset packet(); has erase packet()

The following transitions have been omitted for clarity: from the Detect, DiscardPacket, ReceiveSave, ReceiveReset, and ReceiveErase states to the Ready state under any condition; the else-transition from the CheckPacket state to the Ready state; and from all states to the Disabled state when device mode != DETECTION.

Figure 11: State machine for compute training task

Input device_mode; reading_vector; are_readings_ready; training_room: uint8

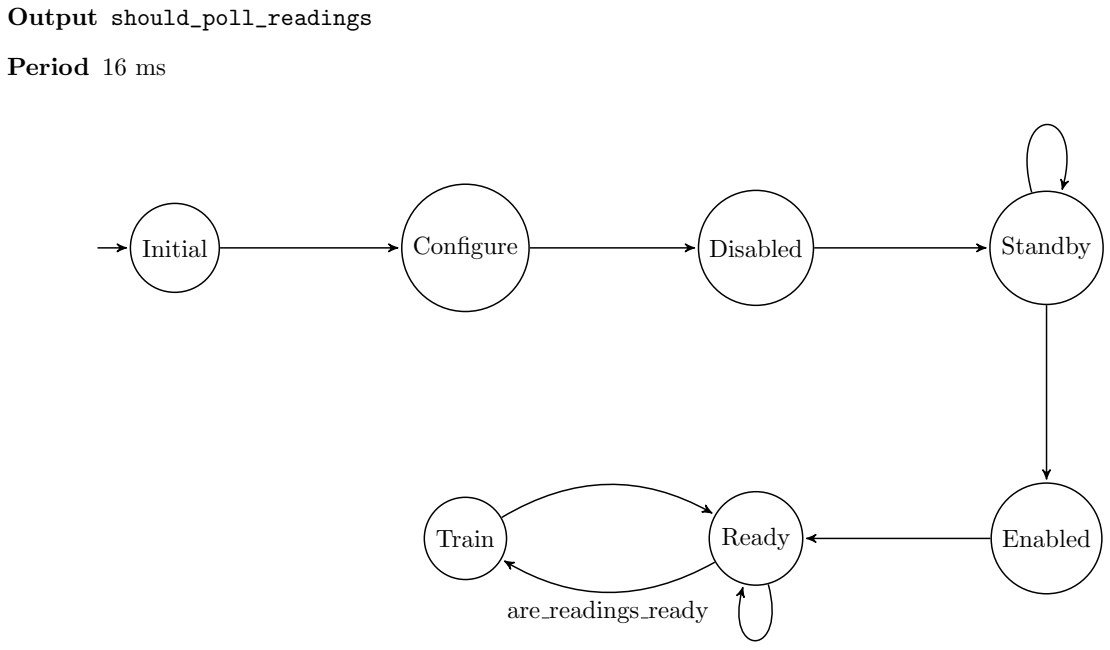
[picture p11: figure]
Output should_poll_readings; Period 16 ms; Initial; Configure; Disabled; Standby; Train; Ready; Enabled; are readings ready

The following transitions have been omitted for clarity: from all states to the Disabled state when device mode != TRAINING.

A.3 Common Infrastructure

Figure 12: State machine for common LCD task

Input should_lcd_clear: bool; should_lcd_write: bool; lcd_buffer: char[]; lcd_position: uint8

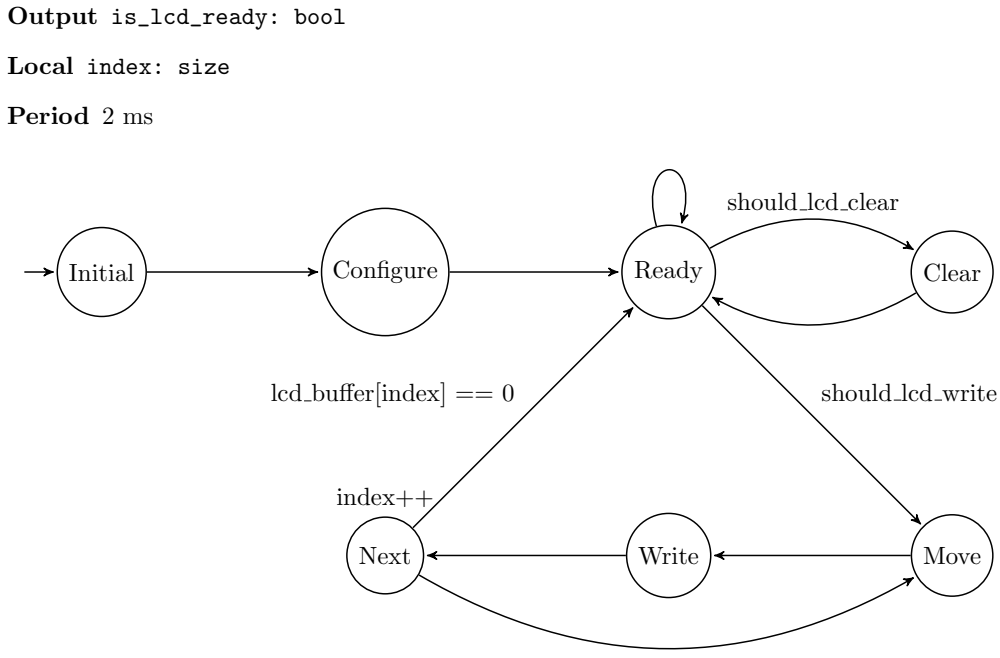
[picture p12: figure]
Output is_lcd_ready: bool; Local index: size; Period 2 ms; Initial; Configure; Ready; Clear; Next; Write; Move; index++; should lcd clear

lcd buffer[index] == 0 | should lcd write / index = 0

Figure 13: State machine for common USART TX task

Input usart_tx_queue: uint8[]; usart_tx_queue_size: size; usart_tx_queue_head: size; usart_tx_queue_tail: size

Output usart_tx_queue

Period 1 ms

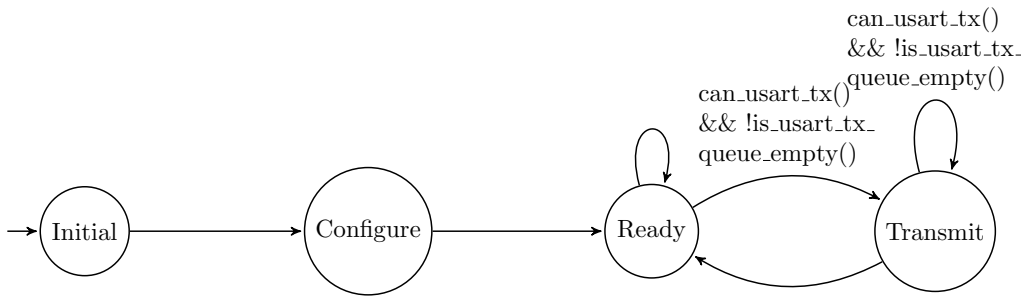
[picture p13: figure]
Initial; Configure; Ready; Transmit; can usart tx() && !is usart tx queue empty()

Figure 14: State machine for common USART RX task

Input usart_rx_queue

Output usart_rx_queue: uint8[]; usart_rx_queue_size: size; usart_rx_queue_head: size;

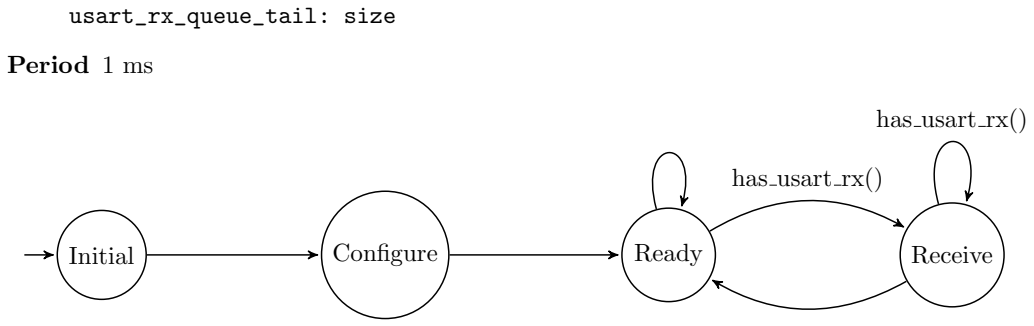
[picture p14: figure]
usart_rx_queue_tail: size; Period 1 ms; Initial; Configure; Ready; Receive; has usart rx()

Figure 15: State machine for common USART packet RX task

Input usart_rx_queue

Output usart_packet_rx_queue: usart_packet[]; usart_packet_rx_queue_size: size; usart_packet_rx_queue_head: size; usart_packet_rx_queue_tail: size

Locals packet: uint8[]; size: size; target_size: size; data_size: size

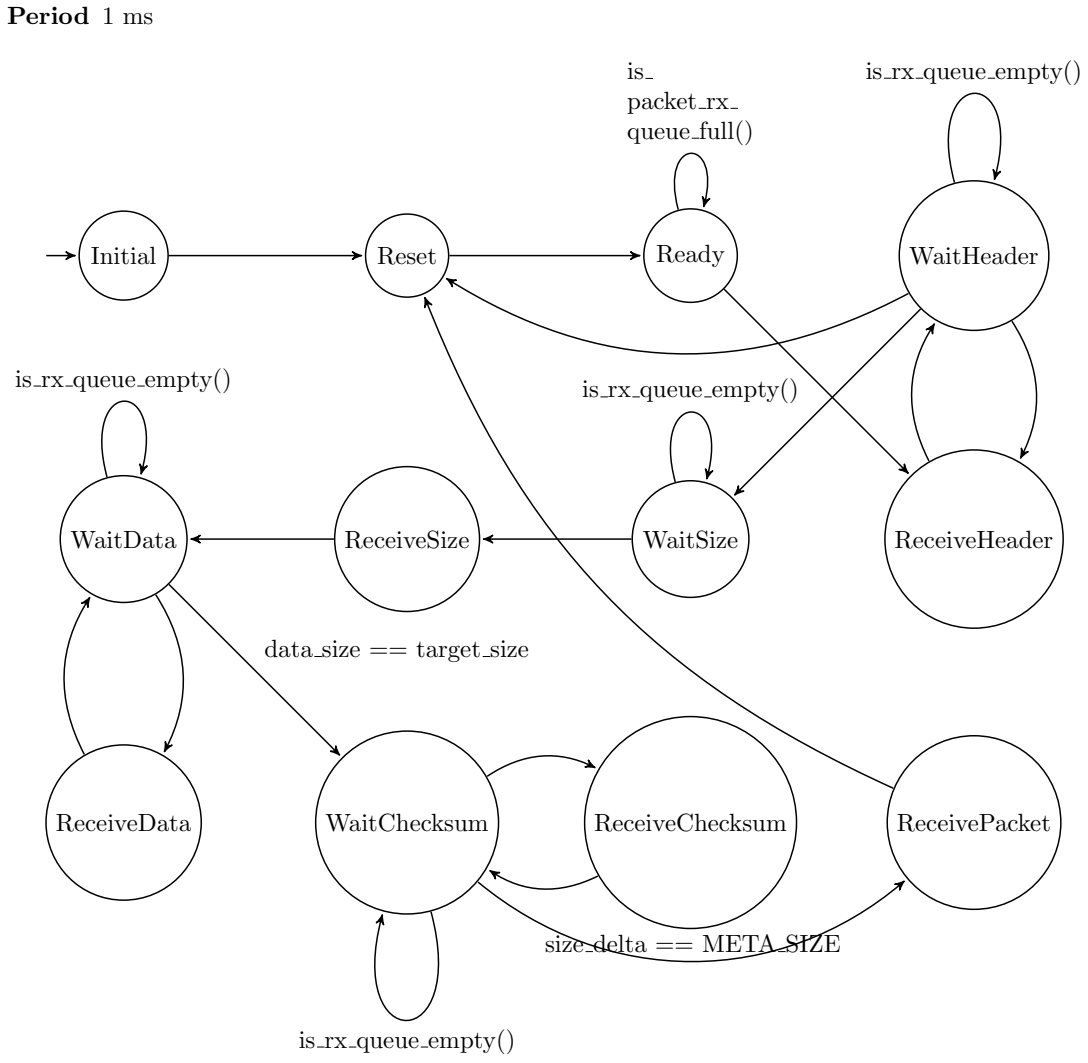
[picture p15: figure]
Period 1 ms; Initial; Reset; Ready; WaitHeader; WaitData; ReceiveSize; WaitSize; ReceiveHeader; ReceiveData; WaitChecksum; ReceiveChecksum; ReceivePacket; is packet rx queue full(); is rx queue empty(); data size == target size; size delta == META SIZE

The transition from the WaitHeader state to the WaitSize state has the condition that size == HEADER SIZE. The transition from the Ready state to the ReceiveHeader state has the condition that has header byte(0) is true. The transition from the WaitHeader state to the ReceiveHeader state has the condition that has header byte(size) is true.

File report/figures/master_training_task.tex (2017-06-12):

\begin{flushleft}
  \begin{description}
    \item [Input]
      \verb#device_mode#;
      \verb#PA1#;
      \verb#PA2#;
      \verb#PA3#
    \item [Output]
      \verb#training_room: uint8#;
      \verb#is_training: bool#;
      \verb#usart_tx_queue#
    \item [Local]
      \verb#tick_count: uint16#
    \item [Period] 20 ms
  \end{description}
\end{flushleft}

\iftoggle{TASKSPECONLY}{}
{
\begin{center}
  \begin{tikzpicture}[->,>=stealth',
      shorten >=1pt,
      node distance=40mm,
      auto,
      on grid,
      semithick]

    \node[state,initial]
      (Initial) {Initial};
    \node[state]
      (Configure) [right=of Initial] {Configure};
    \node[state]
      (Standby) [right=of Configure] {Standby};
    \node[state]
      (Disabled) [right=of Standby] {Disabled};
    \node[state]
      (Enabled) [below=of Initial] {Enabled};
    \node[state]
      (Ready) [right=of Enabled] {Ready};
    \node[state]
      (Inc) [below=of Ready] {Inc};
    \node[state]
      (IncHold) [below=of Inc] {IncHold};
    \node[state]
      (Dec) [left=of Inc] {Dec};
    \node[state]
      (DecHold) [below=of Dec] {DecHold};
    \node[state]
      (Training) [right=of Ready] {Training};
    \node[state]
      (Confirm) [below=of Training] {Confirm};
    \node[state]
      (ConfirmWait) [below=of Confirm] {ConfirmWait};

    \path[->]
      (Initial) edge node {} (Configure)
      (Configure) edge node {} (Standby)
      (Disabled) edge node {} (Standby)
      (Standby) edge node {} (Enabled)
      (Enabled) edge node {} (Ready)
      (Ready) edge [bend right, align = left] node {PA3} (Dec)
      (Ready) edge [align = left] node {PA2} (Inc)
      (Ready) edge [align = left] node {PA1} (ConfirmWait)
      (Ready) edge [loop above] node {} (Ready)
      (Inc) edge [bend left, align = left] node {PA2 /\\tick\_count\\= 0} (IncHold)
      (IncHold) edge [bend left, align = left] node {PA2} (Inc)
      (IncHold) edge [loop below, align = left] node {PA2 \&\& tick\_count $<$\\BUTTON\_REPEAT\_\\TICKS} (IncHold)
      (Dec) edge [bend left, align = left] node {PA3 /\\tick\_count\\= 0} (DecHold)
      (DecHold) edge [bend left, align = left] node {PA3} (Dec)
      (DecHold) edge [loop below, align = left] node {PA3 \&\& tick\_count $<$\\BUTTON\_REPEAT\_\\TICKS} (DecHold)
      (ConfirmWait) edge [loop below] node {is\_usart\_tx\_queue\_full()} (ConfirmWait)
      (ConfirmWait) edge node {} (Confirm)
      (Confirm) edge node {} (Training)
      (Training) edge [loop above] node {} (Training);

  \end{tikzpicture}
\end{center}

The following transitions have been omitted for clarity: from all states
to the Disabled state, under the condition that device\_mode !=
TRAINING; and the else-transitions from the Inc, IncHold, Dec, and
DecHold states to the Ready state.  The transition conditions from the
Ready state to the Dec, Inc, and ConfirmWait states are also conjoined
with the condition that PA1 + PA2 + PA3 == 1.  The transition conditions
from the DecHold and IncHold states to the Dec and Inc states,
respectively, are also conjoined with the condition that tick\_count ==
BUTTON\_REPEAT\_TICKS.

}

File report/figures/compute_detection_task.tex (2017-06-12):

\begin{flushleft}
  \begin{description}
    \item [Input]
      \verb#device_mode#;
      \verb#reading_vector#;
      \verb#are_readings_ready#
    \item [Output]
      \verb#detected_room: uint8#;
      \verb#should_poll_readings#
    \item [Period] 16 ms
  \end{description}
\end{flushleft}

\iftoggle{TASKSPECONLY}{}
{
\begin{center}
  \begin{tikzpicture}[->,>=stealth',
      shorten >=1pt,
      node distance=41mm,
      auto,
      on grid,
      semithick]

    \node[state,initial]
      (Initial) {Initial};
    \node[state]
      (Configure) [right=of Initial] {Configure};
    \node[state]
      (Disabled) [right=of Configure] {Disabled};
    \node[state]
      (Standby) [right=of Disabled] {Standby};
    \node[state]
      (Enabled) [below of=Initial] {Enabled};
    \node[state]
      (Ready) [right of=Enabled] {Ready};
    \node[state]
      (Detect) [below of=Enabled] {Detect};
    \node[state]
      (CheckPacket) [right of=Ready] {CheckPacket};
    \node[state]
      (DiscardPacket) [right of=CheckPacket] {DiscardPacket};
    \node[state]
      (ReceiveReset) [below of=CheckPacket] {ReceiveReset};
    \node[state]
      (ReceiveSave) [left of=ReceiveReset] {ReceiveSave};
    \node[state]
      (ReceiveErase) [right of=ReceiveReset] {ReceiveErase};

    \path[->]
      (Initial) edge node {} (Configure)
      (Configure) edge node {} (Disabled)
      (Disabled) edge node {} (Standby)
      (Standby) edge [loop above] node {} (Standby)
      (Standby) edge node {} (Enabled)
      (Enabled) edge node {} (Ready)
      (Ready) edge [align=left] node {!is\_usart\_\\packet\_rx\_\\queue\_empty()} (CheckPacket)
      (Ready) edge node {are\_readings\_ready} (Detect)
      (Ready) edge [loop below] node {} (Ready)
      (CheckPacket) edge [align=left] node {!is\_packet\_\\good()} (DiscardPacket)
      (CheckPacket) edge [align=left] node {has\_save\_\\packet()} (ReceiveSave)
      (CheckPacket) edge [align=left] node {has\_reset\_\\packet()} (ReceiveReset)
      (CheckPacket) edge [align=left] node {has\_erase\_\\packet()} (ReceiveErase);

  \end{tikzpicture}
\end{center}

The following transitions have been omitted for clarity: from the
Detect, DiscardPacket, ReceiveSave, ReceiveReset, and ReceiveErase
states to the Ready state under any condition; the else-transition from
the CheckPacket state to the Ready state; and from all states to the
Disabled state when device\_mode != DETECTION.

}

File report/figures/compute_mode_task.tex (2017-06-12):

\begin{flushleft}
  \begin{description}
    \item [Input]
      \verb#usart_packet_rx_queue#
    \item [Output]
      \verb#device_mode: enum#;
      \verb#training_room: uint8#
    \item [Period] 16 ms
  \end{description}
\end{flushleft}

\iftoggle{TASKSPECONLY}{}
{
\begin{center}
  \begin{tikzpicture}[->,>=stealth',
      shorten >=1pt,
      node distance=41mm,
      auto,
      on grid,
      semithick]

    \node[state,initial]
      (Initial) {Initial};
    \node[state]
      (Configure) [right=of Initial] {Configure};
    \node[state]
      (Ready) [right=of Configure] {Ready};
    \node[state]
      (CheckPacket) [below of=Ready] {CheckPacket};
    \node[state]
      (DiscardPacket) [below of=Initial] {DiscardPacket};
    \node[state]
      (ReceiveDetection) [below of=CheckPacket] {ReceiveDetection};
    \node[state]
      (ReceiveTraining) [below of=DiscardPacket] {ReceiveTraining};

    \path[->]
      (Initial) edge node {} (Configure)
      (Configure) edge node {} (Ready)
      (Ready) edge [align=left] node {!is\_usart\_\\packet\_rx\_\\queue\_empty()} (CheckPacket)
      (Ready) edge [loop right] node {} (Ready)
      (CheckPacket) edge node {!is\_packet\_good()} (DiscardPacket)
      (CheckPacket) edge node {has\_detection\_packet()} (ReceiveDetection)
      (CheckPacket) edge node {has\_training\_packet()} (ReceiveTraining);

  \end{tikzpicture}
\end{center}

The following transitions have been omitted for clarity: from the
DiscardPacket, ReceiveDetection, and ReceiveTraining states to the Ready
state under any condition.

}

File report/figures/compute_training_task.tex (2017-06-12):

\begin{flushleft}
  \begin{description}
    \item [Input]
      \verb#device_mode#;
      \verb#reading_vector#;
      \verb#are_readings_ready#;
      \verb#training_room: uint8#
    \item [Output]
      \verb#should_poll_readings#
    \item [Period] 16 ms
  \end{description}
\end{flushleft}

\iftoggle{TASKSPECONLY}{}
{
\begin{center}
  \begin{tikzpicture}[->,>=stealth',
      shorten >=1pt,
      node distance=41mm,
      auto,
      on grid,
      semithick]

    \node[state,initial]
      (Initial) {Initial};
    \node[state]
      (Configure) [right=of Initial] {Configure};
    \node[state]
      (Disabled) [right=of Configure] {Disabled};
    \node[state]
      (Standby) [right=of Disabled] {Standby};
    \node[state]
      (Enabled) [below of=Standby] {Enabled};
    \node[state]
      (Ready) [left of=Enabled] {Ready};
    \node[state]
      (Train) [left of=Ready] {Train};

    \path[->]
      (Initial) edge node {} (Configure)
      (Configure) edge node {} (Disabled)
      (Disabled) edge node {} (Standby)
      (Standby) edge [loop above] node {} (Standby)
      (Standby) edge node {} (Enabled)
      (Enabled) edge node {} (Ready)
      (Ready) edge [bend left] node {are\_readings\_ready} (Train)
      (Ready) edge [loop below] node {} (Ready)
      (Train) edge [bend left] node {} (Ready);

  \end{tikzpicture}
\end{center}

The following transitions have been omitted for clarity:  from all
states to the Disabled state when device\_mode != TRAINING.

}

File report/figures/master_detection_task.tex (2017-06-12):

\begin{flushleft}
  \begin{description}
    \item [Input]
      \verb#device_mode#;
      \verb#PA2#;
      \verb#PA3#
    \item [Output]
      \verb#detected_room: uint8#;
      \verb#usart_tx_queue#
    \item [Local]
      \verb#tick_count: uint16#
    \item [Period] 20 ms
  \end{description}
\end{flushleft}

\iftoggle{TASKSPECONLY}{}
{
\begin{center}
  \begin{tikzpicture}[->,>=stealth',
      shorten >=1pt,
      node distance=42mm,
      auto,
      on grid,
      semithick]

    \node[state,initial]
      (Initial) {Initial};
    \node[state]
      (Configure) [right=of Initial] {Configure};
    \node[state]
      (Standby) [right=of Configure] {Standby};
    \node[state]
      (Disabled) [right=of Standby] {Disabled};
    \node[state]
      (Enabled) [below=of Initial] {Enabled};
    \node[state]
      (Ready) [right=of Enabled] {Ready};
    \node[state]
      (Reset) [below=of Ready] {Reset};
    \node[state]
      (ResetHold) [below=of Reset] {ResetHold};
    \node[state]
      (Save) [left=of Reset] {Save};
    \node[state]
      (SaveHold) [below=of Save] {SaveHold};
    \node[state]
      (CheckPacket) [right=of Ready] {CheckPacket};
    \node[state]
      (DiscardPacket) [right=of CheckPacket] {DiscardPacket};
    \node[state]
      (ReceiveDetection) [below=of DiscardPacket] {ReceiveDetection};
    \node[state]
      (Erase) [below=of ReceiveDetection] {Erase};
    \node[state]
      (EraseHold) [above left=of Erase] {EraseHold};

    \path[->]
      (Initial) edge node {} (Configure)
      (Configure) edge node {} (Standby)
      (Disabled) edge node {} (Standby)
      (Standby) edge node {} (Enabled)
      (Enabled) edge node {} (Ready)
      (Ready) edge [bend right, align = left] node {PA2 + PA3 == 1\\\&\& PA2} (Save)
      (Ready) edge [bend left, align = left] node {PA2 + PA3 == 1\\\&\& PA3} (Reset)
      (Ready) edge [align = left] node {!is\_usart\_\\packet\_rx\_\\queue\_empty()} (CheckPacket)
      (Ready) edge [loop above] node {} (Ready)
      (Save) edge node {PA2} (SaveHold)
      (SaveHold) edge [loop below] node {PA2} (SaveHold)
      (Reset) edge [align = left] node {PA3 /\\tick\_count = 0} (ResetHold)
      (ResetHold) edge [align = left] node {PA3 \&\& tick\_count ==\\ERASE\_HOLD\_TICKS} (Erase)
      (ResetHold) edge [loop below, align = left] node {PA3 \&\& tick\_count $<$\\ERASE\_HOLD\_TICKS} (ResetHold)
      (Erase) edge node {PA3} (EraseHold)
      (EraseHold) edge [loop above] node {PA3} (EraseHold)
      (CheckPacket) edge node {has\_detection\_packet()} (ReceiveDetection)
      (CheckPacket) edge node {} (DiscardPacket);

  \end{tikzpicture}
\end{center}

The following transitions have been omitted for clarity: from all states
to the Disabled state, under the condition that device\_mode !=
DETECTION; and the else-transitions from the DiscardPacket,
ReceiveDetection, Save, Reset, Erase, SaveHold, ResetHold, and EraseHold
states to the Ready state.

}

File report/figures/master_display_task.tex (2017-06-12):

\begin{flushleft}
  \begin{description}
    \item [Input]
      \verb#detected_room#;
      \verb#training_room#;
      \verb#is_training#;
      \verb#should_display_save#;
      \verb#should_display_reset#;
      \verb#should_display_erase#;
      \verb#is_lcd_ready#
    \item [Output]
      \verb#should_lcd_clear#;
      \verb#should_lcd_write#;
      \verb#lcd_buffer#;
      \verb#lcd_position#
    \item [Local]
      \verb#last_room: uint8#
    \item [Period] 20 ms
  \end{description}
\end{flushleft}

\iftoggle{TASKSPECONLY}{}
{
\begin{center}
  \begin{tikzpicture}[->,>=stealth',
      shorten >=1pt,
      node distance=41mm,
      auto,
      on grid,
      semithick]

    \node[state,initial]
      (Initial) {Initial};
    \node[state]
      (Configure) [right=of Initial] {Configure};
    \node[state]
      (ChangeMode) [right=of Configure] {ChangeMode};
    \node[state]
      (DetectionEnter) [below=of Configure] {DetectionEnter};
    \node[state]
      (DetectionReady) [left=of DetectionEnter] {DetectionReady};
    \node[state]
      (DispNoDetectWait) [below=of DetectionReady] {DispNoDetectWait};
    \node[state]
      (DispNoDetect) [below=of DispNoDetectWait] {DispNoDetect};
    \node[state]
      (TrainingReady) [below=of ChangeMode] {TrainingReady};
    \node[state]
      (TrainingEnter) [right=of TrainingReady] {TrainingEnter};
    \node[state]
      (DispSelectWait) [below right of=TrainingReady] {DispSelectWait};
    \node[state]
      (DispSelect) [below of=DispSelectWait] {DispSelect};
    \node[state]
      (DispTrainWait) [below left of=TrainingReady] {DispTrainWait};
    \node[state]
      (DispTrain) [below of=DispTrainWait] {DispTrain};

    \path[->]
      (Initial) edge node {} (Configure)
      (Configure) edge node {} (ChangeMode)
      (ChangeMode) edge [bend right, align=left] node {device\_mode ==\\DETECTION} (DetectionEnter)
      (ChangeMode) edge [align=left] node {device\_mode ==\\TRAINING} (TrainingEnter)
      (DetectionEnter) edge [bend left=20] node {} (DispNoDetectWait)
      (DetectionReady) edge [align=left] node {last\_room !=\\detected\_room} (DispNoDetectWait)
      (DetectionReady) edge [loop above] node {} (DetectionReady)
      (DispNoDetect) edge [bend left=45] node {} (DetectionReady)
      (DispNoDetectWait) edge node {is\_lcd\_ready} (DispNoDetect)
      (DispNoDetectWait) edge [loop right] node {} (DispNoDetectWait)
      (TrainingEnter) edge node {} (DispSelectWait)
      (TrainingReady) edge [bend right=20, align=left] node {training\_room !=\\last\_room} (DispSelectWait)
      (TrainingReady) edge [bend right=30, align=left] node {is\_training} (DispTrainWait)
      (TrainingReady) edge [loop right] node {} (TrainingReady)
      (DispSelect) edge [bend left] node {} (TrainingReady)
      (DispSelectWait) edge node {is\_lcd\_ready} (DispSelect)
      (DispSelectWait) edge [loop left] (DispSelectWait)
      (DispTrain) edge [bend right] node {} (TrainingReady)
      (DispTrainWait) edge node {is\_lcd\_ready} (DispTrain)
      (DispTrainWait) edge [loop left] (DispTrainWait);

  \end{tikzpicture}
\end{center}

The following transitions have been omitted for clarity: from all states
to the ChangeMode state, under the condition that device\_mode is
different from the expected mode for the given state.  The
DispNoDetectWait and DispNoDetect states are duplicated, including
transitions, for the following similar states: Detect, Save, Reset, and
Erase.  These redundant states have been omitted for clarity.

}

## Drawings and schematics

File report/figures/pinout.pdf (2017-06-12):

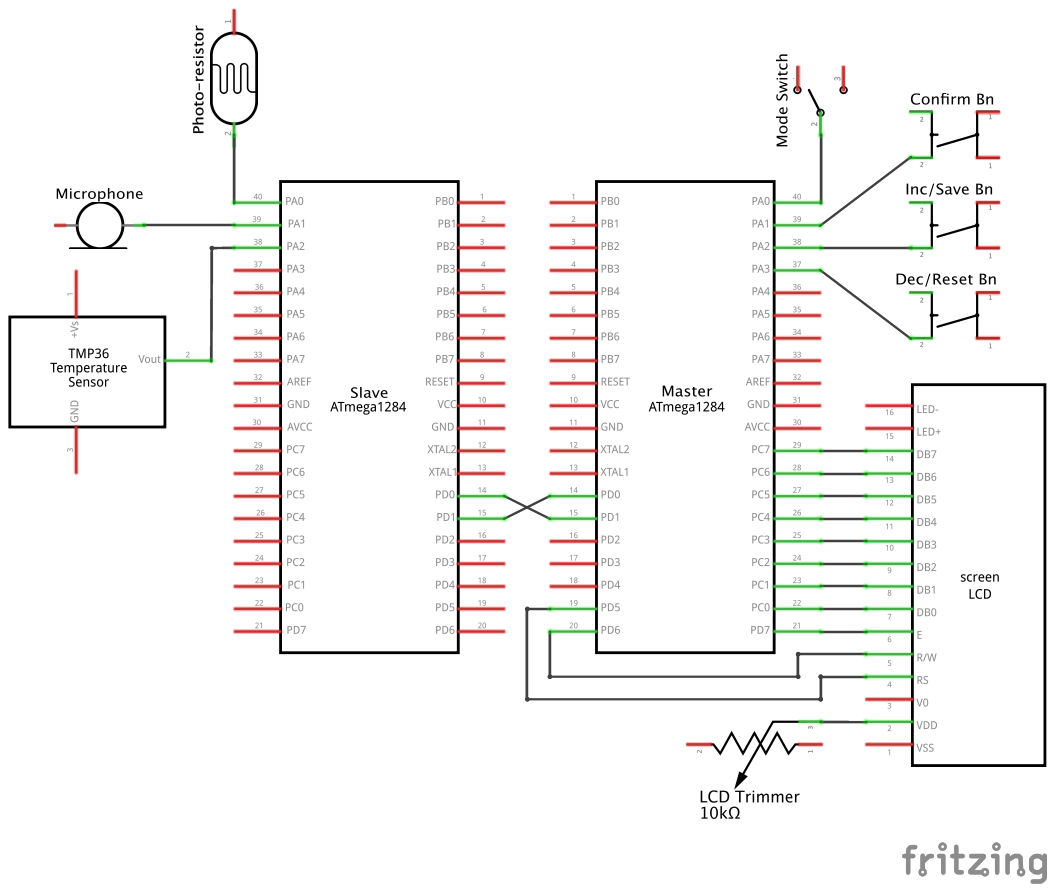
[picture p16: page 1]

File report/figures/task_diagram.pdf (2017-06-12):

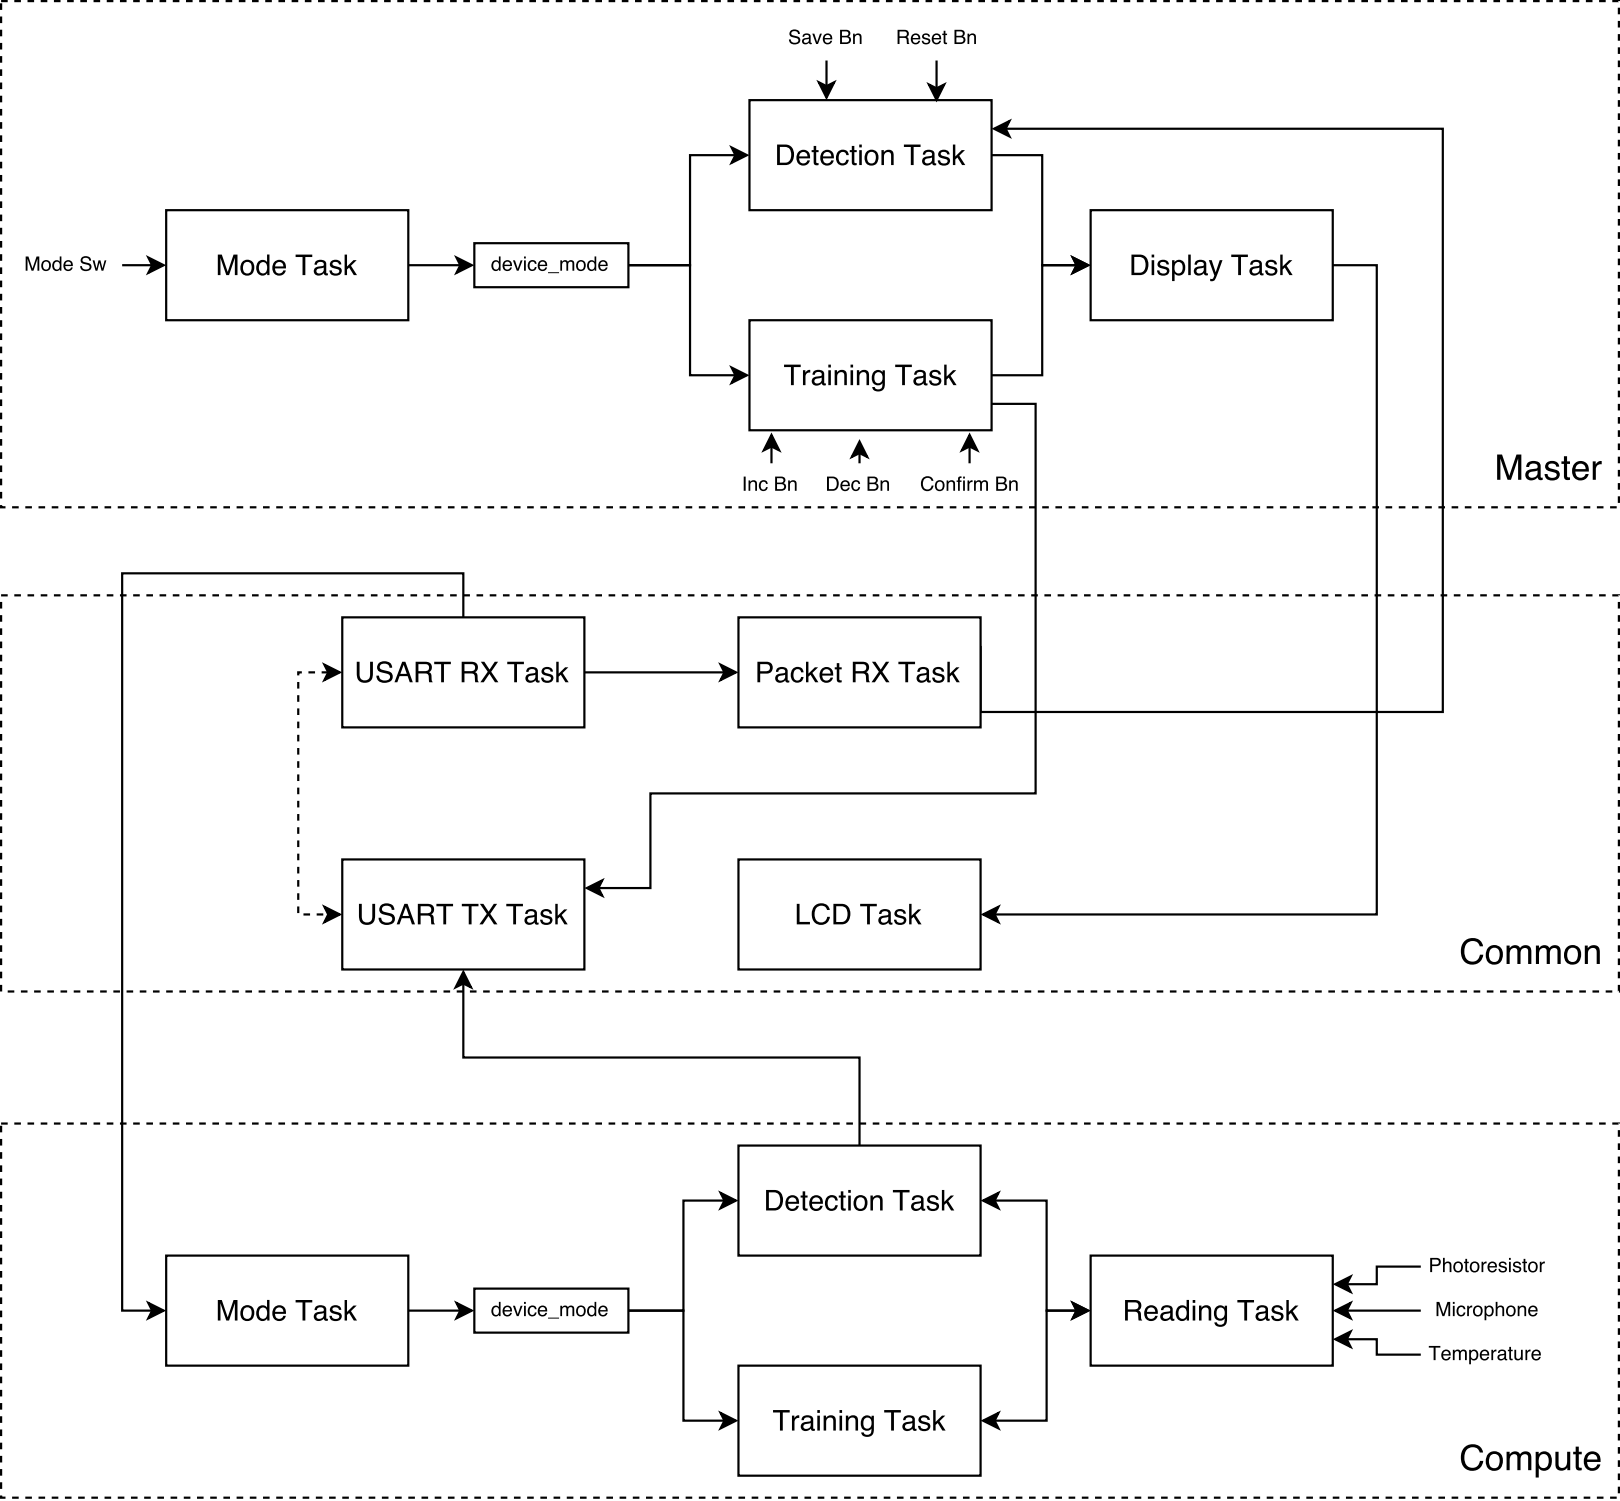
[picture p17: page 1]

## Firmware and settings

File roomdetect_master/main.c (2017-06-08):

// main.c
// Jeremiah Griffin <jgrif007@ucr.edu>
// Lab Section: 23
// Assignment: Custom Project - Room Detector - Master Application
//
// I acknowledge all content contained herein, excluding template or example
// code, is my own original work.

#include "detection_task.h"
#include "display_task.h"
#include "mode_task.h"
#include "training_task.h"
#include "lcd_task.h"
#include "schedule.h"
#include "usart_packet_rx_task.h"
#include "usart_rx_task.h"
#include "usart_tx_task.h"
#include <stddef.h>

int main()
{
    schedule_task(&lcd_task);
    schedule_task(&usart_tx_task);
    schedule_task(&usart_rx_task);
    schedule_task(&usart_packet_rx_task);
    schedule_task(&mode_task);
    schedule_task(&detection_task);
    schedule_task(&training_task);
    schedule_task(&display_task);
    run_schedule();
}

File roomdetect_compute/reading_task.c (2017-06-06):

// reading_task.c
// Jeremiah Griffin <jgrif007@ucr.edu>
// Lab Section: 23
// Assignment: Custom Project - Room Detector - Compute Application
//
// I acknowledge all content contained herein, excluding template or example
// code, is my own original work.

#include "reading_task.h"
#include "adc.h"
#include <string.h>

#define SAMPLE_SIZE 16

enum {
    STATE_INITIAL,
    STATE_CONFIGURE,
    STATE_STANDBY,
    STATE_POLL,
    STATE_START,
    STATE_WAIT,
    STATE_READ,
    STATE_NEXT,
    STATE_OUTPUT,
};

static task_state_t tick(task_state_t state)
{
    static const adc_pin_t pins[MODEL_VECTOR_SIZE] = {
        ADC_PIN_0, ADC_PIN_1, ADC_PIN_2,
    };
    static accum readings[MODEL_VECTOR_SIZE];
    static size_t index;
    static size_t samples;

    // Transitions
    switch (state) {
        case STATE_INITIAL:
            state = STATE_CONFIGURE;
            break;

        case STATE_CONFIGURE:
            state = STATE_STANDBY;
            break;

        case STATE_STANDBY:
            if (should_poll_readings) {
                state = STATE_POLL;
            }
            else {
                state = STATE_STANDBY;
            }
            break;
            
        case STATE_POLL:
            state = STATE_START;
            break;

        case STATE_START:
            state = STATE_WAIT;
            break;

        case STATE_WAIT:
            if (is_adc_ready()) {
                state = STATE_READ;
            }
            else {
                state = STATE_WAIT;
            }
            break;

        case STATE_READ:
            if (index == MODEL_VECTOR_SIZE) {
                state = STATE_NEXT;
            }
            else {
                state = STATE_START;
            }
            break;
            
        case STATE_NEXT:
            if (samples == SAMPLE_SIZE) {
                state = STATE_OUTPUT;
            }
            else {
                state = STATE_START;
            }
            break;

        case STATE_OUTPUT:
            state = STATE_STANDBY;
            break;

        default:
            state = STATE_INITIAL;
            break;
    }

    // Actions
    switch (state) {
        case STATE_CONFIGURE:
            enable_adc();
            break;
            
        case STATE_POLL:
            index = 0;
            samples = 0;
            for (size_t i = 0; i < MODEL_VECTOR_SIZE; ++i) {
                readings[i] = 0K;
            }
            break;

        case STATE_START:
            select_adc_pin(pins[index]);
            start_adc();
            are_readings_ready = false;
            should_poll_readings = false;
            break;

        case STATE_READ:
            readings[index] += read_adc_voltage();
            ++index;
            break;
            
        case STATE_NEXT:
            index = 0;
            ++samples;
            break;

        case STATE_OUTPUT:
            for (size_t i = 0; i < MODEL_VECTOR_SIZE; ++i) {
                reading_vector[i] = readings[i] / (accum)SAMPLE_SIZE;
            }
            are_readings_ready = true;
            break;

        default:
            break;
    }

    return state;
}

task_t reading_task = {
    STATE_INITIAL, // Initial state
    tick,          // Tick function
    1,             // Millisecond period
};
accum reading_vector[MODEL_VECTOR_SIZE];
bool are_readings_ready;
bool should_poll_readings;

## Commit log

2017-06-01 Add initial code for room detector project
    Most of the code included is modified from the code in liblab, with
    the notable exception of the USART interfaces, including low-level
    functions, a byte queue receiver task, a byte queue transmitter
    task, a packet encoder/decoder, and a packet queue receiver task.
    Also included are two test programs for the master and compute
    microcontrollers. The compute microcontroller polls readings from
    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
2017-06-06 Fix adc_to_volts function using correct casting
    [adc.c]
2017-06-06 Add sample smoothing to the reading task using the mean
2017-06-06 Use root-mean square to calculate total z-score
    Use sample formula for standard deviation rather than population
    for sufficiently large sample sizes
2017-06-08 Reduce number of buttons to 3
    Merge save and increment buttons
    Merge reset and decrement buttons
2017-06-12 Add pinout diagram created with Fritzing
    [pinout.fzz]
